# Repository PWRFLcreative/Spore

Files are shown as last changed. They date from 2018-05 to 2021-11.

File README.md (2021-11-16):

# Spore
The Spore system is a hardware and software platform that simplifies the process of creating with light. Each Spore is a softball-sized, WiFi-controlled, addressable, battery-operated, RGB LED module. This platform affords control of 1-1000+ Spores working together. The current version is optimized for about 100 Spores.

Spore was developed to showcase the potential of [Lightwork](https://github.com/PWRFLcreative/Lightwork). Lightwork uses computer vision to quickly map complex arrangements of addressable lights. Spore allows individually addressable LEDs to be placed in almost any arrangement, without any wiring for power and data. Used together, the the time to conceive and deploy a spatial light installation can be reduced from days to minutes.

With lots of options for input and output, Spore has many other possibilities for future uses. For example, wireless motor drivers that can be location mapped (using the LEDs + Lightwork), or accelerometer input to interact with individual lights, or reconfigurable, location aware sensor network interfaces, or lights that interpret the weather, or big Daniel Rozin-esque mirrors, etc...

## Basic Operation Requirements
  * Multicast capable Router + 802.11n Access Point (tested with Ubiquiti UAP-AC-LR + EdgeRouter X for ~100 devices). See network setup below.
  * JST-EH charger(s). 5V, ~520mA per Spore - we use a 5V 30A supply to charge 50 at a time
  * Source of sACN (E1.31) - generates the LED colors and transmits over the network
  * Between 1 and 100 Spores.

## Quick Start
1. Make sure you have at least one charged Spore, and have completed the [install guide](#installationrun-instructions) for the Config App and [Network setup](#network-setup).
2. Join your newly created network.
3. Once you’re all set up, open the Config App, and click `Send Server IP`. This broadcasts your computer's IP to all Spores on the network so that they can connect to you.
4. Next click `Scan for Changes`. This will scan your network and assign a unique address to all connected Spores, starting at `1`.
5. Click `Spore Status` to open the monitor, this will show you which Spores are connected, their battery level, and firmware version.
6. Use the mode switches to make sure they’re all communicating properly, e.g. switch from blackout to test mode.
7. Switch them into Normal Mode so they can receive sACN data.
8. Send sACN over multicast. We’ve used [QLC+](https://www.qlcplus.org/) and [sACN View](https://sourceforge.net/projects/sacnview/) to test, but you could also use something like Touchdesigner.

That’s it! Now that your Spores are set up and receiving sACN, you can map them with Lightwork, or use them as you’d like.

# Table of Contents
* [Hardware](#hardware)
  + [Feature List](#feature-list)
  + [Dev Requirements](#dev-requirements)
  + [PCB Build/Assembly/Ordering](#pcb-buildassemblyordering)
  + [Battery](#battery)
  + [Enclosure](#enclosure)
  + [Network Setup](#network-setup)
* [Firmware](#firmware)
  + [Dev Requirements](#dev-requirements)
  + [Compile/Upload Instructions](#compileupload-instructions)
* [Software](#software)
  + [Feature List](#feature-list)
  + [Dev Requirements](#dev-requirements)
  + [Installation/Run Instructions](#installationrun-instructions)
  + [OTA Firmware Updates](#ota-firmware-updates)
  + [Function Reference](#function-reference)
* [FAQ](#faq)
* [Known Issues & Workarounds](#known-issues--workarounds)
* [TODO](#todo)
* [Credits](#credits)

# Hardware
This section covers info on building and modifying the hardware, including the PCBs, batteries, prototyping, network setup, and enclosures.  

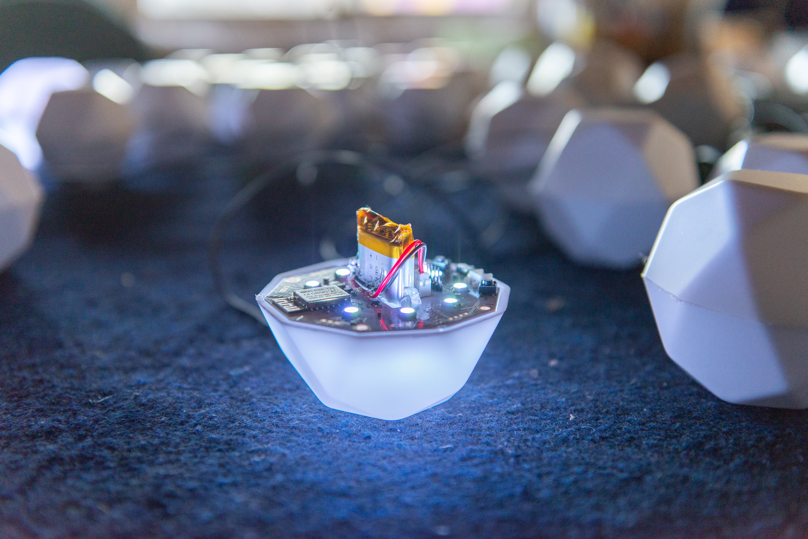
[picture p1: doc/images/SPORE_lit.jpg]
Image of Open Spores


## Feature List
  * ESP8266 - An Arduino-compatible microcontroller with built-in wifi
  * 16 built-in addressable RGB LEDs (sk6812)
  * Built-in battery charger (@500mA)
  * Slot for 1800mAh lipo (single cell, 103450)
  * Lasts 5+ hours w/ 1800mAh cell
  * Breakout pins for:
    + more LEDs
    + built-in MOSFET (~2.5A)
    + I2C
    + analog input (reads VBatt by default)
    + motor output
    + servo output
  * sACN (E1.31) LED control over network
  * Fades to black if no data received for more than 3 seconds
  * Over-The-Air (OTA) updateable firmware (all at once!)

## Dev Requirements
Install KiCad and open it! -- The PCB was designed in [KiCad 4](http://kicad.org/). We recently did test import to KiCad 5 which seemed OK, but we haven’t tested exported files/gerbers yet. We usually check our gerbers using [gerbv](https://sourceforge.net/projects/gerbv/) and/or GerbView included in KiCad 5 (the one in KiCad 4 is not great).  

### If You Don't Have a Spore:
If you want to play with the firmware without actually building one of the boards, this is our recommended test hardware (but use what you have):

  * [Adafruit HUZZAH Feather](https://www.adafruit.com/product/2821)
  * [NeoPixel ring](https://www.adafruit.com/product/1463)
  * A single cell LiPo, ~500-2000mAh (e.g. [Adafruit 500mAh](https://www.adafruit.com/product/1578))

Connect the NeoPixel `Data Input` to `RX` on HUZZAH; NeoPixel `Power 5V DC` to `BAT` on HUZZAH; NeoPixel `Power Signal Ground` to `GND` on HUZZAH. This setup works great for other form-factors. You could build a whole system using these or something similar if you wanted!

Connecting the LED 5V to the battery instead of 5V allows you to send 3.3V data without using a level shifter.

>**Note:** The LED data pin must go to GPIO3 for DMA (Direct Memory Access) to work. DMA lets the ESP send data to the LEDs without flickering during WiFi events. Otherwise, WiFi events take enough processor cycles to throw off the timing for the super-sensitive neopixel-compatible LEDs.. and it looks terrible!

## PCB Build/Assembly/Ordering
Some notes on ordering PCBs & parts:

I’ve had good experience getting assembled boards from [SAPA Technologies](http://www.sapatechs.com/) in the Vancouver BC area, and both assembled and unpopulated boards from PCBWay and Elecrow in China (but there are lots that are good). Local fabs generally do better, faster work, and allow you to come visit/send couriers/perform tests to make sure things happen right the first time; but it is naturally more expensive (I’ve found around 40-100% more). Cheaper chinese assemblers do a fine job, but it can take a little longer, communication is slow (time zones!), and you kinda get one shot at a time. One run I did in China had a silly mistake made by the fabricator that needed to be fully re-done twice. That put us over 6 weeks behind schedule. Apart from that, I recommend ordering at least 15% over what you actually need if ordering overseas, and more like 5-10% or less for local (depending on your test procedures and quantities).

>**Note:** Assembled means “with all the components soldered on”. Turnkey assembly means “source and buy all the components for me, and then solder them on”. Unpopulated (usually called PCB Manufacturing, or PCB Prototype) means, “just the PCB” and I am responsible for sourcing, buying, and soldering the components.

We usually order our components for local assembly or prototyping from Digikey. I recommend getting addressable LEDs from [Shiji Lighting](http://www.shiji-led.com/) if you are doing a bunch. They have consistent quality, excellent service, and good prices. You can use RGB or RGBW sk6812s for this board (RGBW will require a firmware modification). I think we didn’t use APA102s/sk9822s to save pins - we needed more free pins for an earlier design concept. That later changed but it was too late to switch back. Feel free to modify the boards for other LED protocols if you prefer!

#### PCB Requirements
When ordering prototype PCBs for Spore online:
  * 2 layers
  * HASL (cheaper) or ENIG/Immersion Gold Finish (a little more corrosion resistant)
  * 1.6mm thickness
  * White Solder Mask (PCB Color) - we think white helps reflect LED light outward vs dark PCB, but do what you want!
  * Leave other options at default

## Battery
SPOREs are designed to use a 103450, 1800mAh lipo battery with JST PHR-2 connector. You can use a different battery, just make sure the polarity of the PHR-2 connector matches, and it is at least 500mAh. The charge current is set with R6 on the Spore board.

We sourced our batteries from General Electronics Battery Co. (http://www.gebattery.co/) and were very happy with the service and quality. You may have to order 100+ batteries with them as they are an OEM supplier. Otherwise check Adafruit/Sparkfun or your local electronics or hobby shop (FYI shipping LiPos from USA to Canada is a pain in the neck).

To install the batteries, we built a simple wooden jig to center and square them in the PCB, tacked them with hot glue, and glued them in with RTV silicone. RTV silicone adheres well to the PCB and the battery, and absorbs shocks without releasing or cracking. It can also handle temperature swings without the bond weakening (e.g. maybe it’s cold outside then your LEDs heat up the board). Make sure it is RTV (room temperature vulcanizing), as neither Silicone I or Silicone II (typical bathroom or door/window sealants) have these properties.

>**Hot Tip:** You can usually find RTV Silicone in the automotive section of Canadian Tire or Home Depot. You can also get it at Princess Auto and Walmart. We love that stuff.

## Enclosure
Files for the enclosure are located [here](hardware/enclosureFiles/).

This includes a solid model for reference, a shell model that can be 3D printed or vacuum formed, and a 2D folded style shell that can be made from paper or translucent sheet material.

We made our shells of vacuum formed, ⅛”, white, Sign-Grade Lexan with the help of the folks at [Dimension 3](http://dimension3plastics.com/). Most of ours are hot-glued together (using a high-temperature gun), so we can easily reconfigure them, which has held up surprisingly well. For more permanent bonds, we’ve had good luck with heavy duty contact cement, 3M 4475 (industrial plastic adhesive), and BSI Maxi-Cure (high quality extra thick CA).

## Network Setup
First set up your network using the Edgerouter setup wizard. Then fire up the UniFi controller and partition your access point with an SSID and password that makes sense to you. We like the SSID: `SPORE`. Make sure the password is at least 8 characters. You'll need to enter these in the firmware `wifi_config.h` file in Arduino before uploading it.

Here are some details for optimizing the recommended Ubiquiti EdgeRouter X router and UAP-AC-xx access point to use multicast:

  * Disable AP multicast filter:  `config.mcast_filter_enabled=false` in config.properties ([Instructions](https://help.ubnt.com/hc/en-us/articles/205146040-UniFi-config-properties-File-Explanation))
  * Adjust AP multicast rate:     `config.mcast_rate.wlan.<your-ssid>=12` also in config.properties
  * in the Unifi Controller Interface Wireless Settings (`https://<your-ip>:8443/manage/site/default/settings/wlans/`), Click `edit/Advanced Options` and disable `Block LAN to WLAN Multicast and Broadcast Data`
  * in `edit/802.11 RATE AND BEACON CONTROLS`, check 2G `Enable Data Rate Control`, and set minimum to 12Mbps.

Additionally, the Unifi Controller and the server both want to use port 8080. Fortunately it is easy to adjust the Unifi controller (and it is not on all the time):

  * Change Unifi Controller http port from 8080 to 8081: `unifi.http.port=8081`in `system.properties` ([Instructions](https://help.ubnt.com/hc/en-us/articles/204910084-UniFi-Change-Default-Ports-for-Controller-and-UAPs))

# Firmware
This section contains information about the Spore firmware. It was written in Arduino which makes it pretty easy to tinker with! Every Spore uses the exact same firmware - addresses are modified using the Config App.

## Dev Requirements
Reminder: [How to Install Arduino Libraries](https://www.arduino.cc/en/Guide/Libraries)
  * [Arduino](https://www.arduino.cc/en/Main/Software) v1.8.7+
  * [Esp8266 Core](https://github.com/esp8266/Arduino#installing-with-boards-manager) v2.4.2 (may not work with older *or* newer version)
  * These Arduino libraries:
    + [Arduino JSON](https://github.com/bblanchon/ArduinoJson) v5.13.2
    + [WebSockets](https://github.com/Links2004/arduinoWebSockets) v2.1.1 (included because it has been modified for [async](https://github.com/Links2004/arduinoWebSockets#esp-async-tcp))
    + [NeoPixelBus](https://github.com/Makuna/NeoPixelBus) v2.3.2
    + [E131](https://github.com/forkineye/E131) v1.0.0
    + [ESPAsyncTCP](https://github.com/me-no-dev/ESPAsyncTCP) v1.2.0 (not in library manager)
    + [OSC](https://github.com/CNMAT/OSC) v1.3.5
    + [FastLED](https://github.com/FastLED/FastLED) v3.2.0
  * FTDI or USB-Serial with compatible pinout. 5V vcc required, 3.3v logic recommended (e.g. [Adafruit CP2104](https://www.adafruit.com/product/3309))

## Compile/Upload Instructions
  * Install Arduino, esp8266 core, and the above libraries
  * Set up Arduino Board options (`Arduino Menu-> Tools/`)  
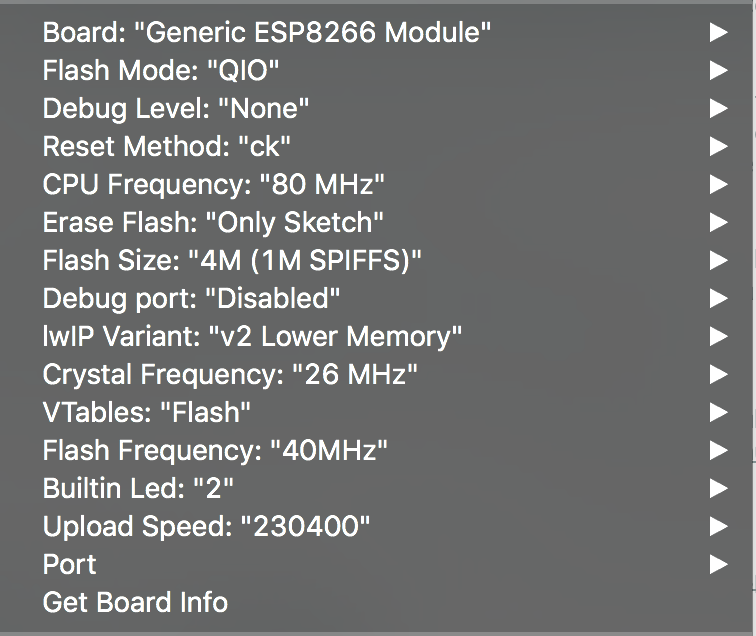
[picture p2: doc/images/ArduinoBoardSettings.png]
Arduino Board Settings
      
    *Note: the order of these settings is not always the same. I have no idea why.*
  * Plug in your FTDI (**check the orientation**) and select the correct port (some USB-Serial converters can handle a higher `Upload Speed`)
  * Set correct SSID and Password in `wifi_config.h` (changes in this file are not tracked by git, so you have to set on every new computer)
  * Open the Arduino Serial Monitor and set the baud rate to `115200`
  * Hold the bootload button while resetting the board, release bootload, then `Arduino Menu-> Sketch/Upload`.
  * ⚠️ **YOU MUST reset the board at least once after uploading new firmware with FTDI or OTA WILL NOT WORK**
  * Use the Serial Monitor to make sure the Spore is connecting to your network and receiving commands from the Config App. Disconnect the FTDI whenever you are done looking at debug printouts!

>**NOTE:** Some USB-Serial converters can prevent the LEDs from updating. If your LEDs seem stuck, unplug your FTDI/USB-Serial Converter.  
>Also: don't forget to download the driver for your USB-Serial converter if it is new!

# Software
The Spore Configuration App is a tool to configure and monitor the Spores. It was built in Node.js using the Electron framework. It should work on Mac, Windows, and GNU/Linux out of the box.

In the near future, we will export compiled binaries for all platforms, but for now, you need to install it using Node.js, and all dependencies should be automatically downloaded on `npm install` (see [below](#installationbuild-instructions)).

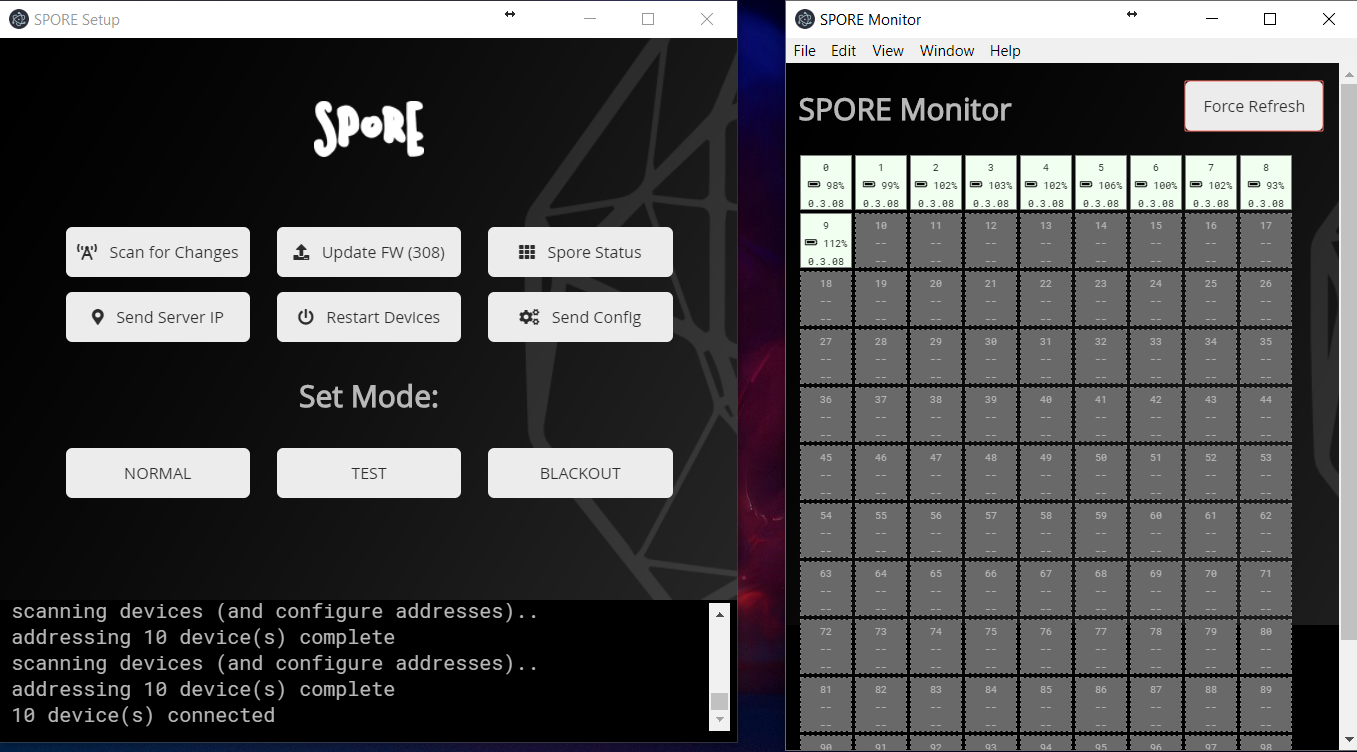
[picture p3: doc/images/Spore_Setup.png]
Configuration App Screenshot


## Feature List
  * Automatically set a unique address for each spore on the network
  * OTA firmware updates
  * Monitor battery level and status of connected spores
    + Red outline of a Spore indicates low battery warning
    + Flashing 🔌/⚠️ icons on a Spore indicate critical battery level
  * Identify individual spores (make a single one light up!) by clicking on it in the Monitor
  * Change modes on all spores:
    + Normal (receive sACN)
    + Test (light up with white, pulsing animation)
    + Blackout (turn off all LEDs)
  * Not required for normal operation of Spores - just a handy tool useful for reconfiguring and troubleshooting

## Dev Requirements
  * Node.js 8 LTS (we developed with v8.11, probably v8.12 is OK, but not yet tested)
  * Decent Javascript-friendly text editor (e.g. Atom, VS Code)

## Installation/Run Instructions
  1. Make sure Node.js is installed (type `node -v` in terminal to verify version. You need v8.11 or v8.12. DO NOT use v10.x+ unless you are ready to fix some stuff
  2. Clone or download and extract this repo to a nice home
  3. Open terminal/cmd
  4. cd to `<this repo>/configApp/` folder in terminal
  5. Type `npm install` to download and install dependencies (will take a few minutes)
  6. Type `npm start` to run
  7. Type `ctrl+c` in terminal to quit

## OTA Firmware Updates
The OTA Firmware updates the firmware on ALL SPOREs connected to the configurator. When the button is pressed, the server sends a message to each SPORE with the latest version number. The SPORE checks to see if this is newer than it’s current version. If yes, then it downloads and installs whichever firmware binary is in the `<this repo>/configApp/firmware/` folder.

  * in Arduino, export the firmware binary (`Menu-> Sketch/Export Compiled Binary`), and copy the output (`<this repo/firmware/Spore/Spore.ino.generic.bin`) to `configApp/firmware/`
  * rename the firmware file to `spore_fw.bin`
  * **After copy and rename:** open `config.json` in the `configApp` folder and change the value of `firmware_version` to match the constant `FW_VERSION` in the `settings.h` of the sensor firmware you just compiled. This number should always be a single `int`, i.e. for version 0.6.01: `601`, for version 1.0.05: `1005`.
  * restart the Config App
  * Press the `Check Firmware (###)` button in the App GUI

This could be more automatic in the future, but having multiple steps forces you to be very intentional about updating the firmware on a bunch of devices at once.

  * ⚠️ You can definitely soft-brick all of your devices by uploading untested firmware.
  * ⚠️ You can break OTA capabilities with untested firmware.
  * ⚠️ Firmware should be testing on a single device before OTA uploads.

Breaking OTA or soft-bricking devices requires updating firmware with FTDI for all of them - I’ve done it, and I don’t recommend it. This will be especially nasty if you've glued the enclosures together with a permanent adhesive.

## Function Reference
**Scan Network** (`websocket`) - Scan network for added or removed Spores, and assign addresses. Caution: this gives all Spores a unique address starting from 1, but in a totally random order. It will definitely change most (or all) addresses of any connected devices. This can ruin any mapping you may have already done!

**Update FW** (`websocket`) - Send command to Spores to check for new firmware. Be sure that your firmware binary works before OTA updating many Spores, or you may need to manually upload over FTDI to fix them.

**Spore Status** (`internal message`) - Opens the Monitor window that shows connected Spores, their firmware version, and battery status.

**Send Server IP** (`UDP OSC`) - broadcast your IP so any Spores on the network can connect to you (This will be automatic on scanning for changes, in a future update). Only needed when switching between computers or networks.

**Restart Devices** (`UDP OSC`)- broadcast a restart message to all Spores on the network. Because this is a UDP broadcast, it will even restart Spores that are having trouble connecting. Feel free to spam it a bit if you are really stuck. *Note: in `config.json`, you can change `reset_broadcast`. `true` brodcasts to all devices over `UDP OSC`, false sends only to connected devices via `websocket`*

**Send Config** (`websocket`) - Send config packet, containing the relevant data from config.json. Currently used to set boot mode on all Spores (Normal: 0, Test: 1, Blackout: 2). Spores store this info in EEPROM and will remember it between power cycles until you change it explicitly.

**Console** (`internal messages`) - This is an output of some system information. The count (`## spore(s) connected`) is not 100% reliable at the moment (related to handshake bug) but it's pretty close. The Monitor is more accurate.

### Modes:
**Normal:** Receive sACN. Fade to black if no sACN received for 3 seconds.

**Test:** Pulsing white animation. Useful to test connectivity and sync with many devices.

**Blackout:** Turn off all device LEDs. Use in conjunction with test mode to make sure all Spores are communicating properly.

### In the monitor:
**Force refresh** (`internal message`) - updates the monitor display. Usually only required after **scan network**. The fact that this is required is a bug. Eventually it will not be needed.

**Green Tiles** are connected Spores

**Grey Tiles** are unconnected Spores (if you only have 20 spores, 80 should be grey).

**Click a connected Spore** (`websocket`) to identify it with a pulsing white animation (Test Mode). Its tile will turn blue and animate a bit. Click again to "unidentify" it. Multiple Spores can be identified at once.

**Red Border Tiles** are Spores with a low battery. When the warning icon starts flashing, the battery is VERY low and they may start behaving badly (random restarts and flickers).

# FAQ
#### What is sACN?
Streaming ACN (sACN), aka ANSI E1.31, is a protocol developed by ESTA to efficiently transport DMX universes over a network. In other words, it is a standard way to control lights over a local network. It is comparable to ArtNET in many aspects. If you’ve ever been to a concert, the stage lights were controlled by DMX, ArtNet, and/or sACN.

Key features are that it uses multicast sockets which reduces network overhead and makes setup easier, and that it has a much higher universe limit of 63,999 vs Artnet’s 32,768. We have also been previously frustrated by apparently mixed standards/version of Artnet (read: it’s broken AF), whereas sACN is an ANSI standard and the implementations we’ve found all seem to work with each other.

#### Do I need the Spore Configurator App?
Maybe. The config app simplifies addressing and firmware updates on lots of devices. You could manage this manually for a small number of devices (i.e. hard-code the address and program with an FTDI). In general, once the devices have been configured once, you don’t need the app running. However, it is very helpful to be able to see connection status, battery status, and firmware version. Also, the remote `Restart Devices` and `Test Mode` are both quick ways to solve problems in the field (“Have you tried turning it off and on?”).

#### Do I need a fancy and expensive router and/or access point?
Depends! For large numbers of devices, access point and router configuration options become more important. In theory, with some good network administration, you should be able to control 1000+ SPOREs. For only a few devices (< 20 or so), any router that supports multicast should work fine, but routers are picky and weird. We can’t promise anything but it doesn’t hurt to try! If you are using your home router, maybe turn off Netflix first.

#### What software can control the SPORE LEDs?
Anything that can send sACN/e1.31 over network. We’ve tested with Lightwork (our own project built in Processing), Touchdesigner (DMX Out Chop), Processing (e131 library), and QLC+ (open source lighting control app). LED control software like Madrix or mapping software like MadMapper should also work. You can use tools like the Open Lighting Architecture (OLA, https://www.openlighting.org/ola/) to communicate with software like Max/MSP, PureData, etc. You could also write some of your own stuff - Arduino, Node.js, c++, python, and others all have sACN libraries available. Or you could modify the SPORE firmware to receive OSC or ArtNet instead.

>TD Lightwork: https://github.com/timrolls/TD-Lightwork

# Known Issues & Workarounds
**Multiple websockets handshake thing** - For some reason, devices sometimes send many "connect" handshakes in a row, even after they have connected. This is probably a firmware problem related to the ESPAsyncTCP + Async Websockets libraries. For now, if a device isn’t connected or repeatedly connects, or repeatedly disconnects - send the `restart devices` command (there is a behaviour in the server that attempts to filter this out, it may take a couple of minutes if your server or router has crashed or been unplugged during operation)

**Address Collision** - currently the system allows multiple devices to have the same address. This has been intentionally allowed for now. If you want each device to have a unique address, press `scan for changes`. HOWEVER, this will readdress everything which will most likely BREAK your mapping (if applicable, e.g. Lightwork). Make sure you have all your devices figured out and address before you map them with Lightwork.

**Changing the Config App `config.json` file** - Whenever this is changed, you should restart the App. Making this more robust is on the future todo list, but it should be so rarely used that restarting the app isn’t the end of the world.

See github issues for more!

# TODO:
Here are some things that might be done in the future. If you want to contribute to the project it might be a good place to start! In no particular order:

  - [ ] See github issues for broken things!
  - [ ] Export Config App as standalone app. For now, you need to install and run it as a dev from your chosen terminal. See the Electron documentation.
  - [ ] Make a SPORE DEMO mode. This should show off capabilities when there is no server or wifi available, or on a button press.
  - [ ] Migrate to Node.js 10 (wait until October for LTS)
  - [ ] Make the firmware server more automatic (drag & drop, rename file, auto-extract version or enter version in GUI)
  - [ ] Make editing the config.json file work better - could be auto-restart server, could be notifies with a warning whenever it changes (i.e. “config file has changed, server restart required”), could be dynamically reload all config values.
  - [ ] Add sleep mode to SPOREs (currently sleep mode is labelled as “blackout” which is also helpful). Would be good to be able to sleep the spores to save battery power if they need to be installed ahead of time. Decisions need to be made about how long between wakeups (to connect to network and check if it’s time to get to work), and which sleep mode to go into.
  - [ ] SPOREs receive other data - Maybe you send it Audio-Reactive OSC or something?
  - [ ] SPOREs transmit streaming data (i.e. streaming their sensor data) - what format, how fast, etc.
  - [ ] Add ArtNet support (we chose sACN because it is more robust, but ArtNet is more widely supported)
  - [ ] Port Config App to Android (wouldn’t it be nice if this whole thing were running on your phone?) - or fork to create a non-electron version that serves the GUI to a browser etc.

## Credits

Spore is a collaboration between [Tangible Interaction](http://www.tangibleinteraction.com/) and [Makerlabs](http://www.makerlabs.com/), made possible by the [Creative BC Interactive Fund](https://www.creativebc.com/programs/development-funding/interactive-fund).

Individual contributors include:

  * Tim Rolls - Creative Director and Developer
  * Leó Stefánsson - Lightwork Developer
  * Brendan Matkin - Spore Hardware, Firmware, Concept
  * Alex Beim - Spore Concept
  * Andrea Buttarini - Spore Design

Special thanks to generous help from volunteers, including:

  * Yasu Harada
  * Marie Harada
  * Noel Rubin
  * Ikbel Hammami

Creative BC Logo

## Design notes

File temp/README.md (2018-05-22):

# Spore
Spore WiFi LED module. Firmware and Hardware.

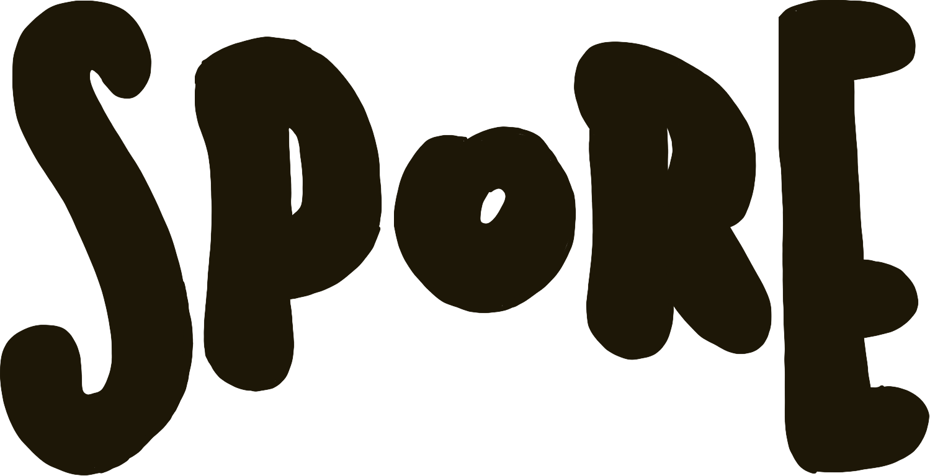
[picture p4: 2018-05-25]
hardware/drawings+img/SPORE.png

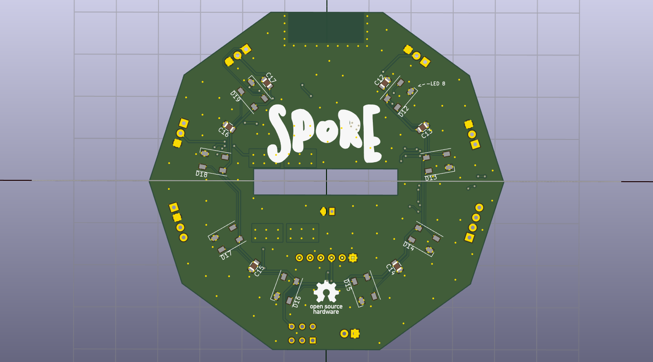
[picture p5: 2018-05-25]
hardware/drawings+img/SPORE_back_v0.0.1.png

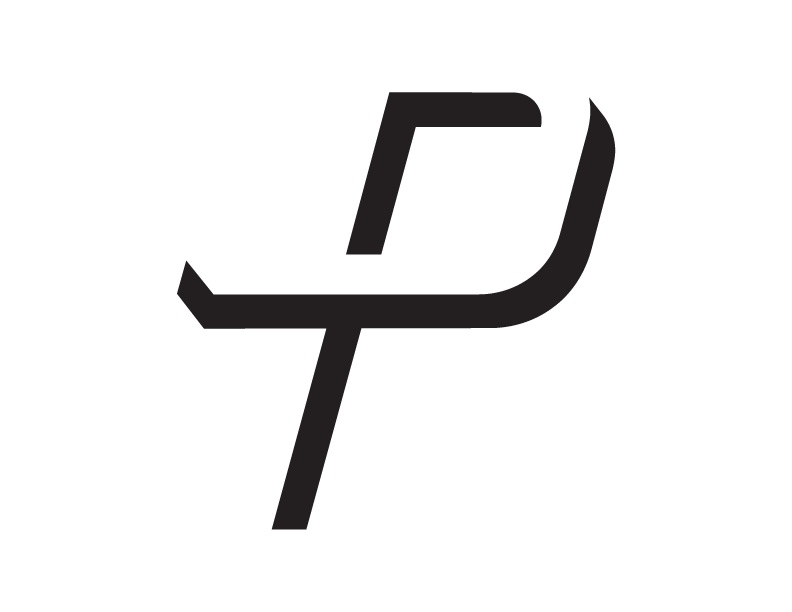
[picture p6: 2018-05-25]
hardware/drawings+img/PWRFL-P-Black.png

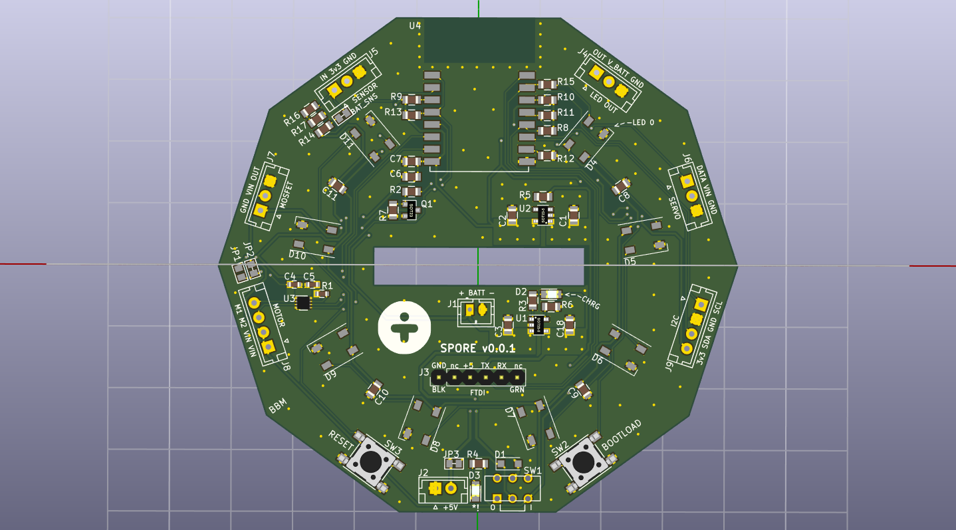
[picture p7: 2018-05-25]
hardware/drawings+img/SPORE_front_v0.0.1.png

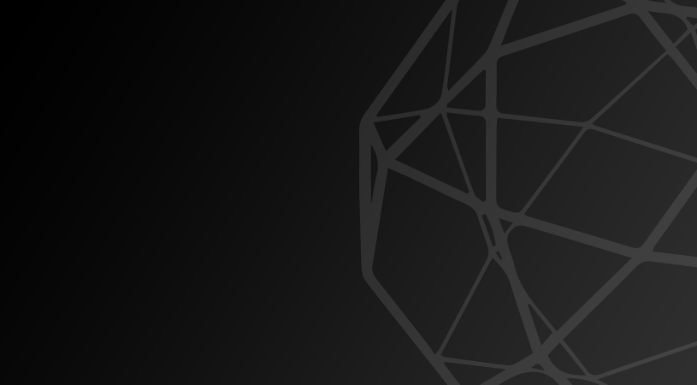
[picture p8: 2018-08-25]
configApp/img/Spore-BG.png

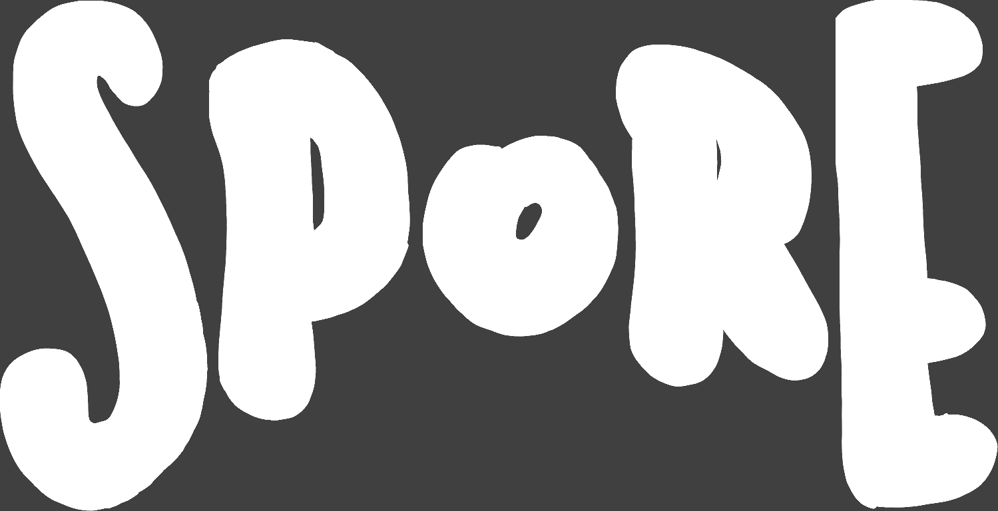
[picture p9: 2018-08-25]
configApp/img/SPORE-White.png

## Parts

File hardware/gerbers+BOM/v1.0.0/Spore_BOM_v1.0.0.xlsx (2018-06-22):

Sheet: Spore_proto
Reference | Value | Footprint | Datasheet | Max ESR | NOTES | TOTALS
C1 | 1.0uF | Capacitors_SMD:C_0805 |  | 1.5 Ohm |  | 0.1uf (0603) | 2 | x
C10 | 1.0uF | Capacitors_SMD:C_0805 |  | 1.5 Ohm |  | 0.1uf (0805) | 2 | x
C11 | 1.0uF | Capacitors_SMD:C_0805 |  | 1.5 Ohm |  | 1.0uf (0805) | 11 | x
C12 | 1.0uF | Capacitors_SMD:C_0805 |  | 1.5 Ohm |  | 2.2uf (0805) | 1 | ~
C13 | 1.0uF | Capacitors_SMD:C_0805 |  | 1.5 Ohm |  | 10uF (0805) | 1 | ~
C14 | 1.0uF | Capacitors_SMD:C_0805 |  | 1.5 Ohm |  | 22uf (0805) | 1 | ~
C15 | 1.0uF | Capacitors_SMD:C_0805 |  | 1.5 Ohm
C16 | 1.0uF | Capacitors_SMD:C_0805 |  | 1.5 Ohm |  | 10k (0603) | 1 | ~
C17 | 1.0uF | Capacitors_SMD:C_0805 |  | 1.5 Ohm |  | 330R (0805) | 1 | ~
C18 | 0.1uF | Capacitors_SMD:C_0805 |  |  |  | 1k (0805) | 1 | x
C2 | 2.2uF | Capacitors_SMD:C_0805 |  | 1.5 Ohm |  | 2k (0805) | 3 | ~
C3 | 10uF | Capacitors_SMD:C_0805 |  | 1.5 Ohm |  | 4.7k (0805) | 2 | ~
C4 | 0.1uF | Capacitors_SMD:C_0603 |  |  | DRV | 10k (0805) | 6 | x
C5 | 0.1uF | Capacitors_SMD:C_0603 |  |  | DRV | 100k (0805) | 2 | ~
C6 | 22uF | Capacitors_SMD:C_0805 |  |  |  | 220k (0805) | 1 | ~
C7 | 0.1uF | Capacitors_SMD:C_0805
C8 | 1.0uF | Capacitors_SMD:C_0805 |  | 1.5 Ohm |  | MBR120 (123F) | 1 | ~
C9 | 1.0uF | Capacitors_SMD:C_0805 |  | 1.5 Ohm |  | SK6812 (5050) | 16 | ~
D1 | MBR120 | Diodes_SMD:D_SOD-123F |  |  |  | White LED (0805) | 2 | ~
D10 | SK6812-RGBW | TI_led:LED_SK6812_PLCC4_5.0x5.0mm_P3.2mm
D11 | SK6812-RGBW | TI_led:LED_SK6812_PLCC4_5.0x5.0mm_P3.2mm |  |  |  | JST PH 2 | 1 | ~
D12 | SK6812-RGBW | TI_led:LED_SK6812_PLCC4_5.0x5.0mm_P3.2mm |  |  |  | JST EH 2 | 1 | ~
D13 | SK6812-RGBW | TI_led:LED_SK6812_PLCC4_5.0x5.0mm_P3.2mm |  |  |  | 6 pin header (2.54mm) | 1 | x
D14 | SK6812-RGBW | TI_led:LED_SK6812_PLCC4_5.0x5.0mm_P3.2mm |  |  |  | JS202011AQN (PTH switch) | 1 | ~
D15 | SK6812-RGBW | TI_led:LED_SK6812_PLCC4_5.0x5.0mm_P3.2mm |  |  |  | PTS645 (SMD Switch) | 2 | ~
D16 | SK6812-RGBW | TI_led:LED_SK6812_PLCC4_5.0x5.0mm_P3.2mm
D17 | SK6812-RGBW | TI_led:LED_SK6812_PLCC4_5.0x5.0mm_P3.2mm |  |  |  | DMG2302UK-7 (SOT-23) | 1 | ~
D18 | SK6812-RGBW | TI_led:LED_SK6812_PLCC4_5.0x5.0mm_P3.2mm |  |  |  | MCP73831 (SOT23-5) | 1 | ~
D19 | SK6812-RGBW | TI_led:LED_SK6812_PLCC4_5.0x5.0mm_P3.2mm |  |  |  | AP2112 (SOT23-5) | 1 | ~
D2 | WHITE | LEDs:LED_0805 |  |  |  | DRV883x (DFN-8 2x2, 0.5mm) | 1 | ~
D3 | WHITE | LEDs:LED_0805 |  |  |  | ESP-12E | 1 | x
D4 | SK6812-RGBW | TI_led:LED_SK6812_PLCC4_5.0x5.0mm_P3.2mm
D5 | SK6812-RGBW | TI_led:LED_SK6812_PLCC4_5.0x5.0mm_P3.2mm
D6 | SK6812-RGBW | TI_led:LED_SK6812_PLCC4_5.0x5.0mm_P3.2mm
D7 | SK6812-RGBW | TI_led:LED_SK6812_PLCC4_5.0x5.0mm_P3.2mm
D8 | SK6812-RGBW | TI_led:LED_SK6812_PLCC4_5.0x5.0mm_P3.2mm
D9 | SK6812-RGBW | TI_led:LED_SK6812_PLCC4_5.0x5.0mm_P3.2mm
J1 | BATT | Connectors_JST:JST_PH_B2B-PH-K_02x2.00mm_Straight
J2 | 5V IN | Connectors_JST:JST_EH_B02B-EH-A_02x2.50mm_Straight
J3 | FTDI to ESP | Pin_Headers:Pin_Header_Straight_1x06_Pitch2.54mm
J4 | LED OUT | Connectors_JST:JST_EH_B03B-EH-A_03x2.50mm_Straight
J5 | SENSOR | Connectors_JST:JST_EH_B03B-EH-A_03x2.50mm_Straight
J6 | SERVO | Connectors_JST:JST_EH_B03B-EH-A_03x2.50mm_Straight
J7 | MOSFET | Connectors_JST:JST_EH_B03B-EH-A_03x2.50mm_Straight
J8 | MOTOR | Connectors_JST:JST_EH_B04B-EH-A_04x2.50mm_Straight
J9 | I2C | Connectors_JST:JST_EH_B04B-EH-A_04x2.50mm_Straight
JP1 | 3v3_EN | TI_conn:JMP_NO
JP2 | EXT_EN | TI_conn:JMP
JP3 | EXT_EN | TI_conn:JMP
JP4 | BATT_SENSE | TI_conn:JMP
Q1 | DMG2302UK-7 | TO_SOT_Packages_SMD:SOT-23 |  |  | MOSFET
R1 | 10k | Capacitors_SMD:C_0603 |  |  | DRV
R10 | 2k | Capacitors_SMD:C_0805 |  |  | I2C
R11 | 2k | Capacitors_SMD:C_0805 |  |  | I2C
R12 | 10k | Capacitors_SMD:C_0805
R13 | 10k | Capacitors_SMD:C_0805
R14 | 100k | Capacitors_SMD:C_0805
R15 | 330 | Capacitors_SMD:C_0805
R16 | 220k | Capacitors_SMD:C_0805
R17 | 100k | Capacitors_SMD:C_0805
R2 | 1k | Capacitors_SMD:C_0805
R3 | 4.7k | Capacitors_SMD:C_0805 |  |  | LED ind.
R4 | 4.7k | Capacitors_SMD:C_0805 |  |  | LED ind.
R5 | 10k | Capacitors_SMD:C_0805
R6 | 2k | Capacitors_SMD:C_0805 |  |  | Charge Prog.
R7 | 10k | Capacitors_SMD:C_0805
R8 | 10k | Capacitors_SMD:C_0805
R9 | 10k | Capacitors_SMD:C_0805
SW1 | JS202011AQN | TI_switches:SW_Micro_DPDT |  |  | PWR
SW2 | Bootload | Buttons_Switches_SMD:SW_SPST_PTS645
SW3 | Reset | Buttons_Switches_SMD:SW_SPST_PTS645
U1 | MCP73831 | TO_SOT_Packages_SMD:SOT-23-5 |  |  | Charger
U2 | AP2112 | TO_SOT_Packages_SMD:SOT-23-5 |  |  | Regulator
U3 | DRV883x | Housings_DFN_QFN:DFN-8-1EP_2x2mm_Pitch0.5mm |  |  | Motor Driver
U4 | ESP-12E | ESP8266:ESP-12E_Brendan |  |  | WiFi

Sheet: BOM
Reference | Description | Footprint | P/N | Digikey | Quantity
C7, C18 | 0.1uf | 0805 |  |  | 2
C1, C8, C9, C10, C11, C12, C13, C14, C15, C16, C17 | 1.0uF | 0805 |  |  | 11
C2 | 2.2uF | 0805 |  |  | 1
C3 | 10uF | 0805 |  |  | 1
C6 | 22uF | 0805 |  |  | 1
R15 | 330R | 0805 |  |  | 1
R2 | 1k | 0805 |  |  | 1
R6 | 2k | 0805 |  |  | 1
R3, R4 | 4k7 | 0805 |  |  | 2
R5, R7 R8, R9, R12, R13 | 10k | 0805 |  |  | 6
R17 | 100k | 0805 |  |  | 1
R14, R16 | 220k | 0805 |  |  | 2
D1 | MBR120 | 123F | MBR120LSFT3G | MBR120LSFT3GOSCT-ND (https://www.digikey.ca/product-detail/en/on-semiconductor/MBR120LSFT3G/MBR120LSFT3GOSCT-ND/6181718) | 1
D4 - D19 | SK6812-RGB | 5050 | SK6812-RGB OR WS2812B | 1528-2388-ND (https://www.digikey.ca/product-detail/en/adafruit-industries-llc/3094/1528-2388-ND/6058485) | 16
D2, D3 | White LED | 0805 | QBLP631-IW | 1516-1085-1-ND (https://www.digikey.ca/product-detail/en/qt-brightek-qtb/QBLP631-IW/1516-1085-1-ND/4814812) | 2
J1 | JST-PH-2 | 2x2.0mm | B2B-PH-K-S(LF)(SN) | 455-1704-ND (https://www.digikey.ca/product-detail/en/jst-sales-america-inc/B2B-PH-K-S(LF)(SN)/455-1704-ND/926611) | 1
J2 | JST-EH-2 | 2x2.54mm | S2B-EH(LF)(SN) | 455-1625-ND (https://www.digikey.ca/product-detail/en/jst-sales-america-inc/S2B-EH(LF)(SN)/455-1625-ND/926533) | 1
J3 | 6 pin header | 6x2.54mm |  |  | 1
SW1 | DPDT Switch | PTS645-SMD | JS202011AQN | 401-2000-ND (https://www.digikey.ca/product-detail/en/c-k/JS202011AQN/401-2000-ND/1640096) | 1
SW2, SW3 | Tactile Switch | PTS645-SMD | PTS645SH50SMTR92 LFS | CKN9085CT-ND (https://www.digikey.ca/product-detail/en/c-k/PTS645SH50SMTR92-LFS/CKN9085CT-ND/1146817) | 2
Q1 | N-ch MOSFET | SOT23 | DMG2302UK-7 | DMG2302UK-7DICT-ND (https://www.digikey.ca/product-detail/en/diodes-incorporated/DMG2302UK-7/DMG2302UK-7DICT-ND/6010163) | 1
U2 | 3.3v Regulator | SOT23-5 | AP2112K-3.3TRG1 | AP2112K-3.3TRG1DICT-ND (https://www.digikey.ca/product-detail/en/diodes-incorporated/AP2112K-3.3TRG1/AP2112K-3.3TRG1DICT-ND/4505257) | 1
U1 | LiPo charge controller | SOT23-5 | MCP73831T-2ACI/OT | MCP73831T-2ACI/OTCT-ND (https://www.digikey.ca/product-detail/en/microchip-technology/MCP73831T-2ACI-OT/MCP73831T-2ACI-OTCT-ND/1979802) | 1
U4 | ESP8266 ESP-12S | ESP-12x | ESP-12S | 1528-1438-ND (https://www.digikey.ca/product-detail/en/adafruit-industries-llc/2491/1528-1438-ND/5761206) | 1

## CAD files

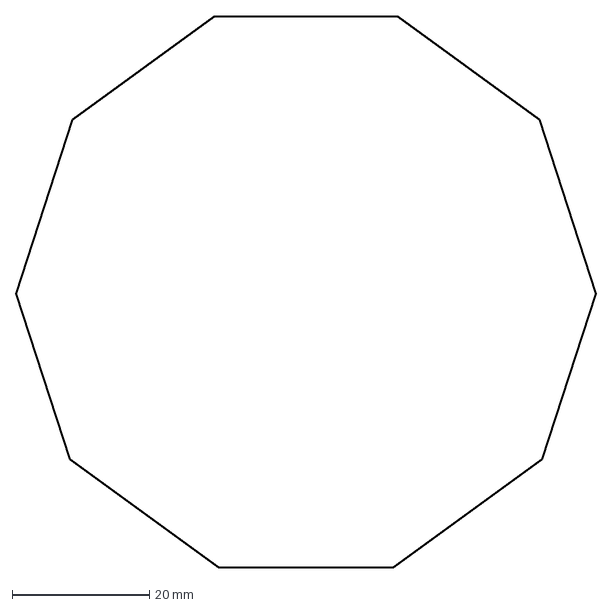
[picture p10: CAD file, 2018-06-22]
hardware/drawings+img/#PCB_mm.dxf
84.5 x 80.3 mm

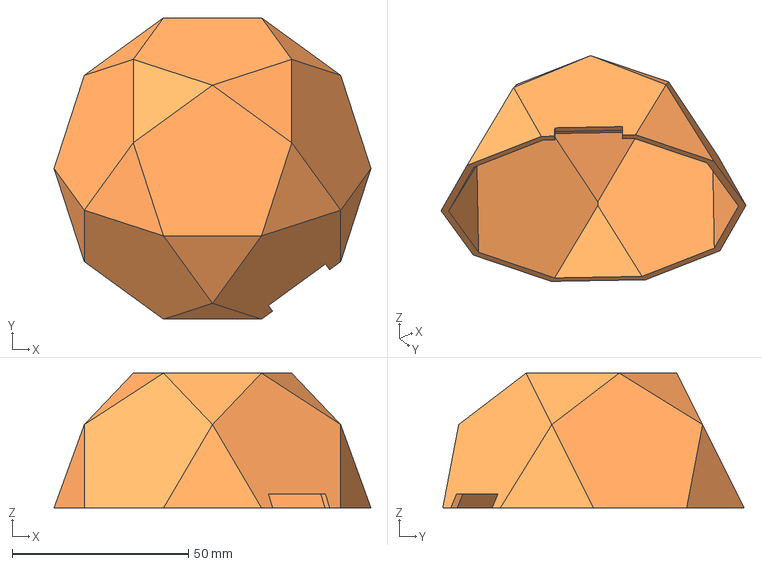
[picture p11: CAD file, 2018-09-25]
hardware/enclosureFiles/Spore Shell 2 of 2 ( with slot ).stp
90.0 x 85.6 x 38.3 mm

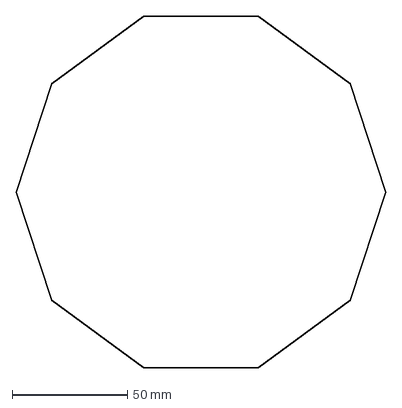
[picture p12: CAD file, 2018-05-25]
hardware/drawings+img/dodecagon_test.dxf
160.0 x 152.2 mm

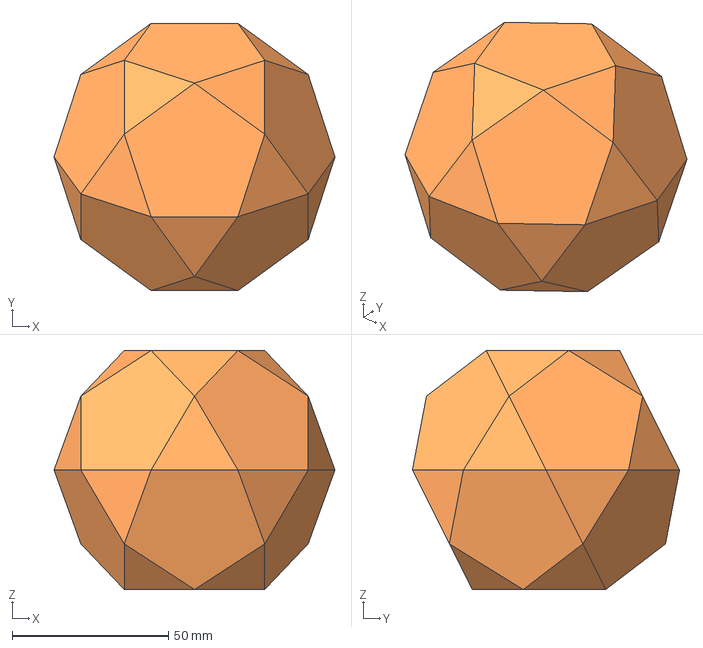
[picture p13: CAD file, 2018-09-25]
hardware/enclosureFiles/Spore Solid.stp
90.0 x 85.6 x 76.6 mm

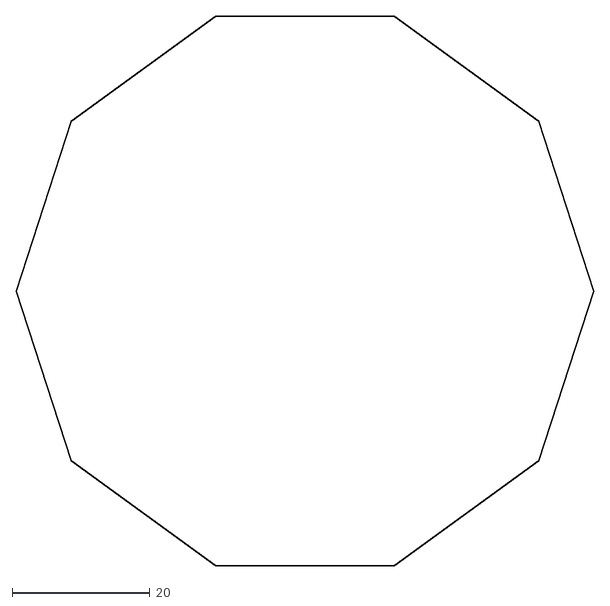
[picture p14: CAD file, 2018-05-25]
hardware/drawings+img/dodecagon_test_84mmD.dxf
84.0 x 79.9

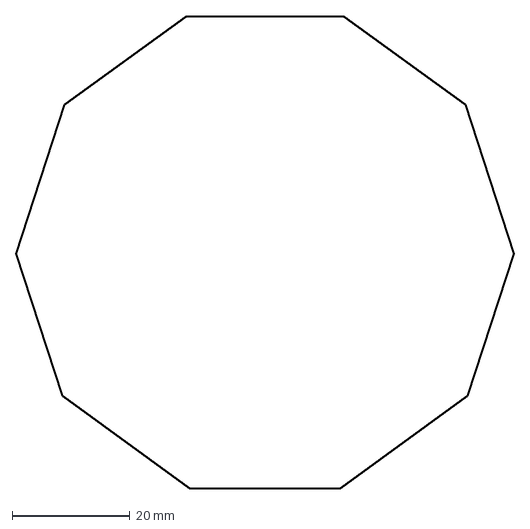
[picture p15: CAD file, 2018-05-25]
hardware/drawings+img/SPORE_PCB_mm.dxf
84.5 x 80.3 mm

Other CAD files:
hardware/enclosureFiles/Spore Shell 1 of 2.stp

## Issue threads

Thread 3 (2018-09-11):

wss.clients.size reporting 1 extra client?

brendanmatkin, 2018-09-11:
in cases with a poor connection, wss.clients.size is too big - i.e. a single device connected and wss.clients.size (can be seen in status console) is 2

brendanmatkin, 2018-09-17:
may also be related to #13

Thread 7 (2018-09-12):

"force refresh" not working (config monitor)

brendanmatkin, 2018-09-12:
used to work, now it doesn't. Have to close and open monitor window after "scan for changes" to get rid of extra, no longer existing devices

brendanmatkin, 2018-09-14:
Additionally, monitor is showing a device in multiple locations after a scan. Closing and re-opening the monitor fixes this.

ALSO some devices flicker in the monitor, but they are not actually loosing their websocket connection.

Need to check the logic in the messaging system between the windows.

brendanmatkin, 2018-09-17:
fixed. Should improve behaviour. see #14

Closed 2018-09-17.

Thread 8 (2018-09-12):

SPORES crash on auto reset when rx change serverIP

brendanmatkin, 2018-09-12:
`exception(28): LoadProhibited: A load referenced a page mapped with an attribute that does not permit loads`
happens with a slightly different stack trace each time.

Related to
```
if (_serverChanged) {
    EEPROM.commit();
    webSocket.begin(serverIP.toString(), wsPort, "/");
    Serial.printf("[osc] New Websocket server at: %s:%u\n", serverIP.toString().c_str(), wsPort);
    //delay(10);
    ESP.restart();
  }
```
in `serverControl.h`

brendanmatkin, 2018-09-14:
This is actually caused by unstable power supply - found by testing without batteries (#9). Throw a big cap on there if you are going to use them without batteries. Closing.

Closed 2018-09-14.

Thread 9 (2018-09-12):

Hardware needs more bulk capacitance?  (if not battery operated)

brendanmatkin, 2018-09-12:
When using without the battery (and just USB), getting weird crashes and inconsistent exceptions. Probably only when using with LEDs - might be related to state of JP3?

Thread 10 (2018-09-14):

Occasional SPORE stuck in ws connect loop

brendanmatkin, 2018-09-14:
On configapp restart, some devices will continually reconnect to the config app on every ping (not sure if hardware ping or config ping). Might be related to #3.

Not sure if this is a firmware issue or config app issue.

brendanmatkin, 2018-09-14:
power-cycling the affected SPORE fixes it.

brendanmatkin, 2018-09-17:
Looks like firmware is sending multiple handshakes. Likely related to async mode (but we can't ditch that now). This might actually be a bug in the library.

Added a "restart devices" ability in the config app as a temp workaround.

Also working on some other config app behaviours that check for already connected devices trying to reconnect and force terminate them until they stop. This is happening too fast though there needs to be some kind of delay in the firmware.

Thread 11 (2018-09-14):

battery voltage math might be wrong

brendanmatkin, 2018-09-14:
SPOREs are power down at a reported remaining capacity of between 20%-25%. Obviously this is wrong! Check the math on both the firwmare and the config app.

brendanmatkin, 2018-09-15:
Not 100% accurate, but remapped the values from 2.75-4.2 to 3.3-4.2, as lower than ~3.1-3.2 and things start to brown out a bit (it fluctuates).

Allowing negative % (i.e. -10% battery life) and adding a flashing plug-in warning below 5% in the config app interface.

Closed 2018-09-15.

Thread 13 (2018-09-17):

do not report "## devices connected" in heartbeat()

brendanmatkin, 2018-09-17:
call a function on interval that checks if wss.clients.size has changes and report.

Currently this happens in heartbeat - this can NEVER reach zero because if zero devices are connected then you will never get a pong and heartbeat won't be called!

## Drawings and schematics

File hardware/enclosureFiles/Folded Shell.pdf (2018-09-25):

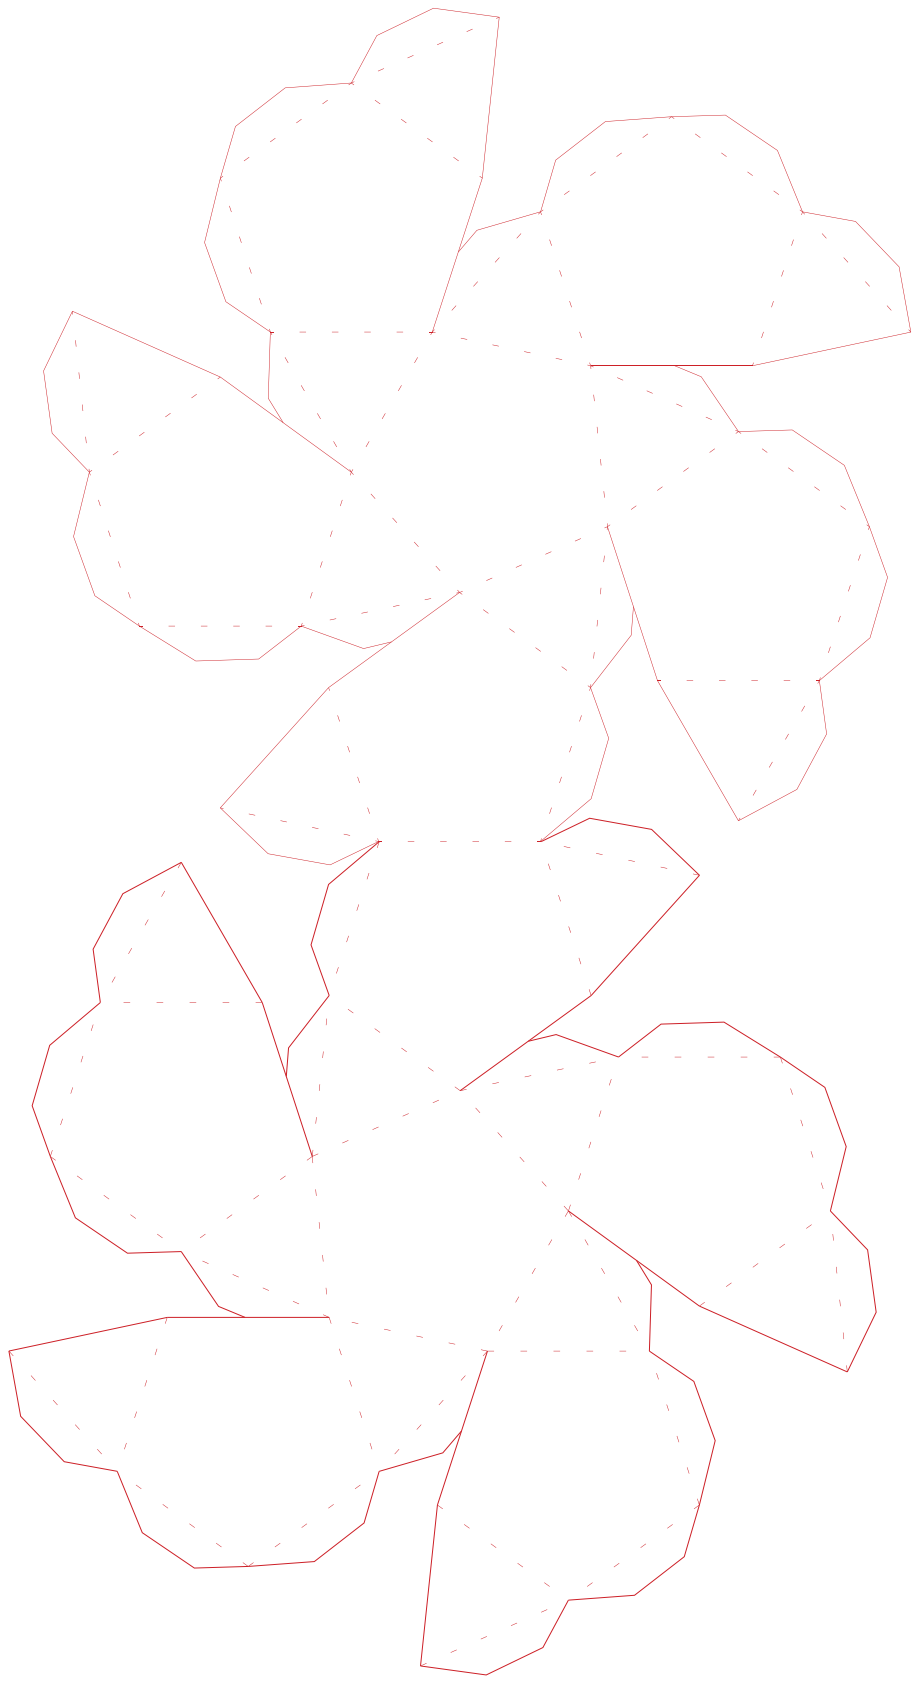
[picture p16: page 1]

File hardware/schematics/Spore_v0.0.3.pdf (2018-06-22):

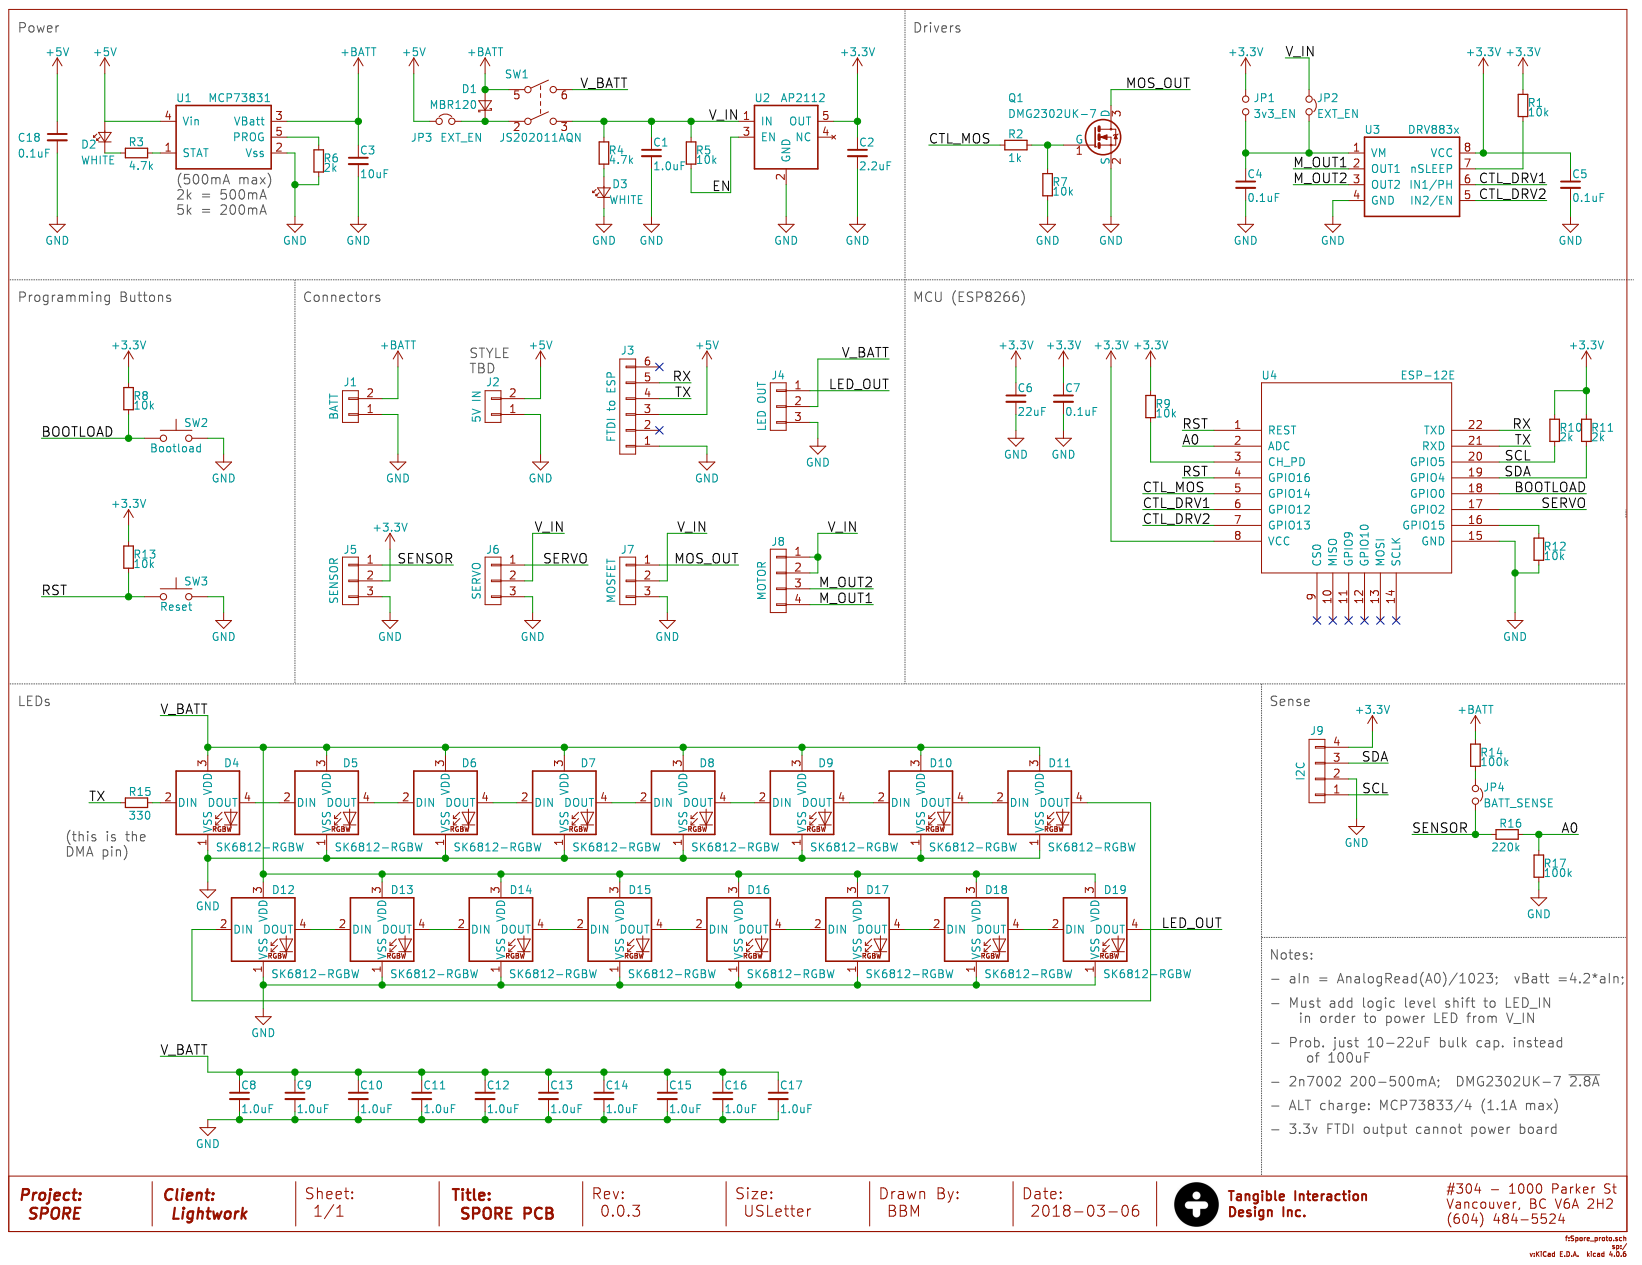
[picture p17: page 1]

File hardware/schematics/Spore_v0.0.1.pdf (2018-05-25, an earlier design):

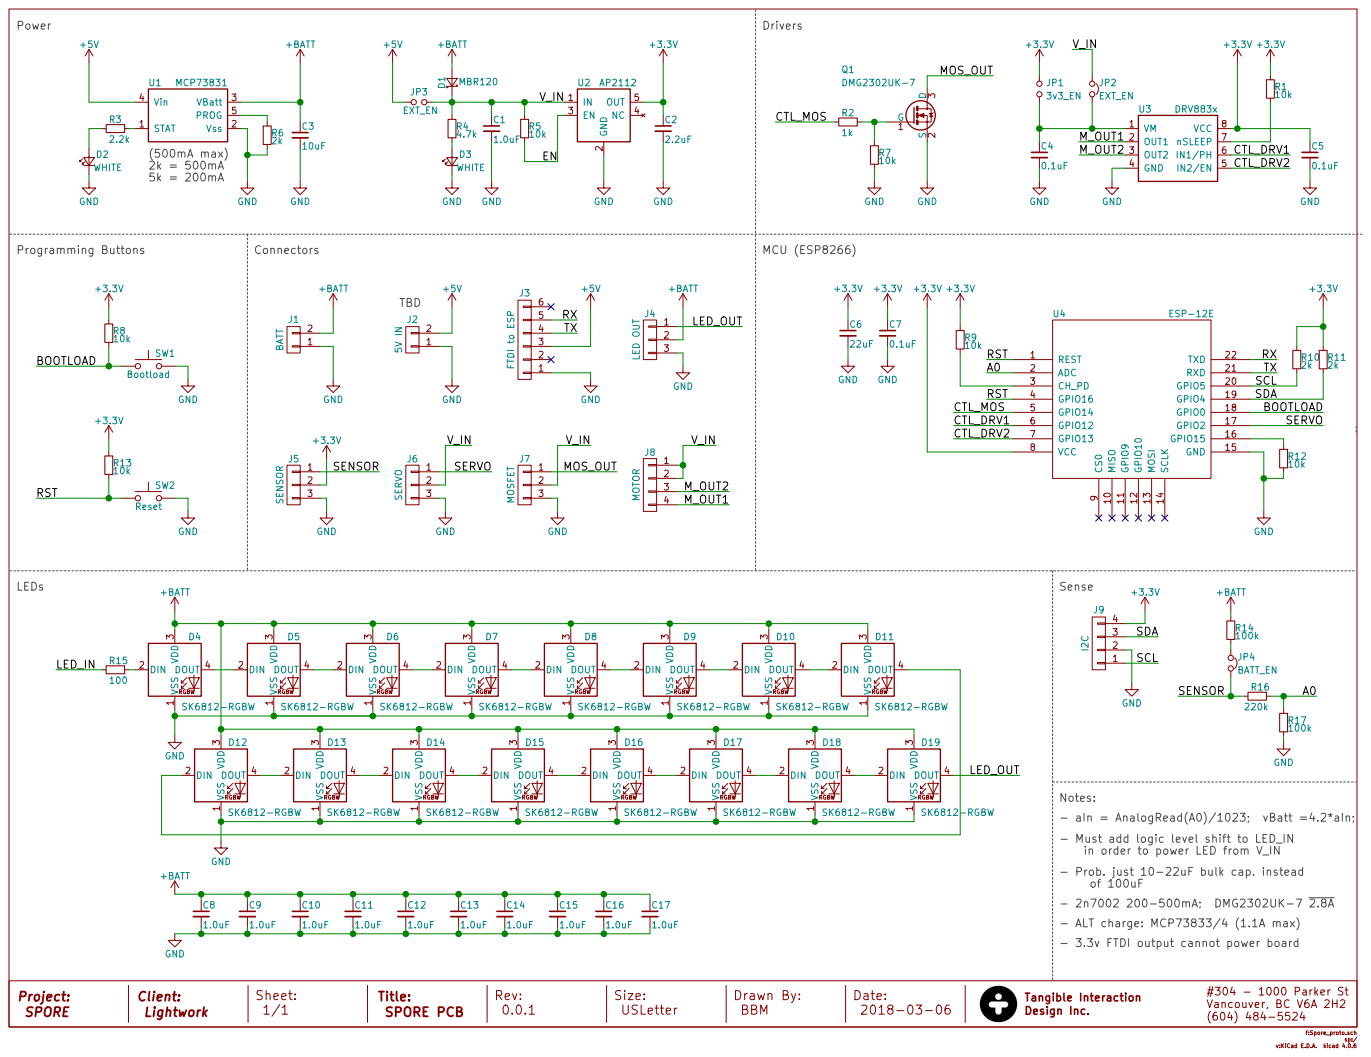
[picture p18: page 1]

9 MISO 10 GPIO5 20 GPIO9 11 RXD 21 GPIO10 12 TXD 22 MOSI 13 SCLK 14 GND 15 GPIO15 16 GPIO2 17 GPIO0 18 GPIO4 19 U4 ESP-12E Power Programming Buttons MCU (ESP8266) 1
+BATT GND

- aIn = AnalogRead(A0)/1023; vBatt =4.2*aIn; C8

- Must add logic level shift to LED_IN
in order to power LED from V_IN
- Prob. just 10-22uF bulk cap. instead
- 2n7002 200-500mA; DMG2302UK-7 2.8A
- ALT charge: MCP73833/4 (1.1A max)
- 3.3v FTDI output cannot power board

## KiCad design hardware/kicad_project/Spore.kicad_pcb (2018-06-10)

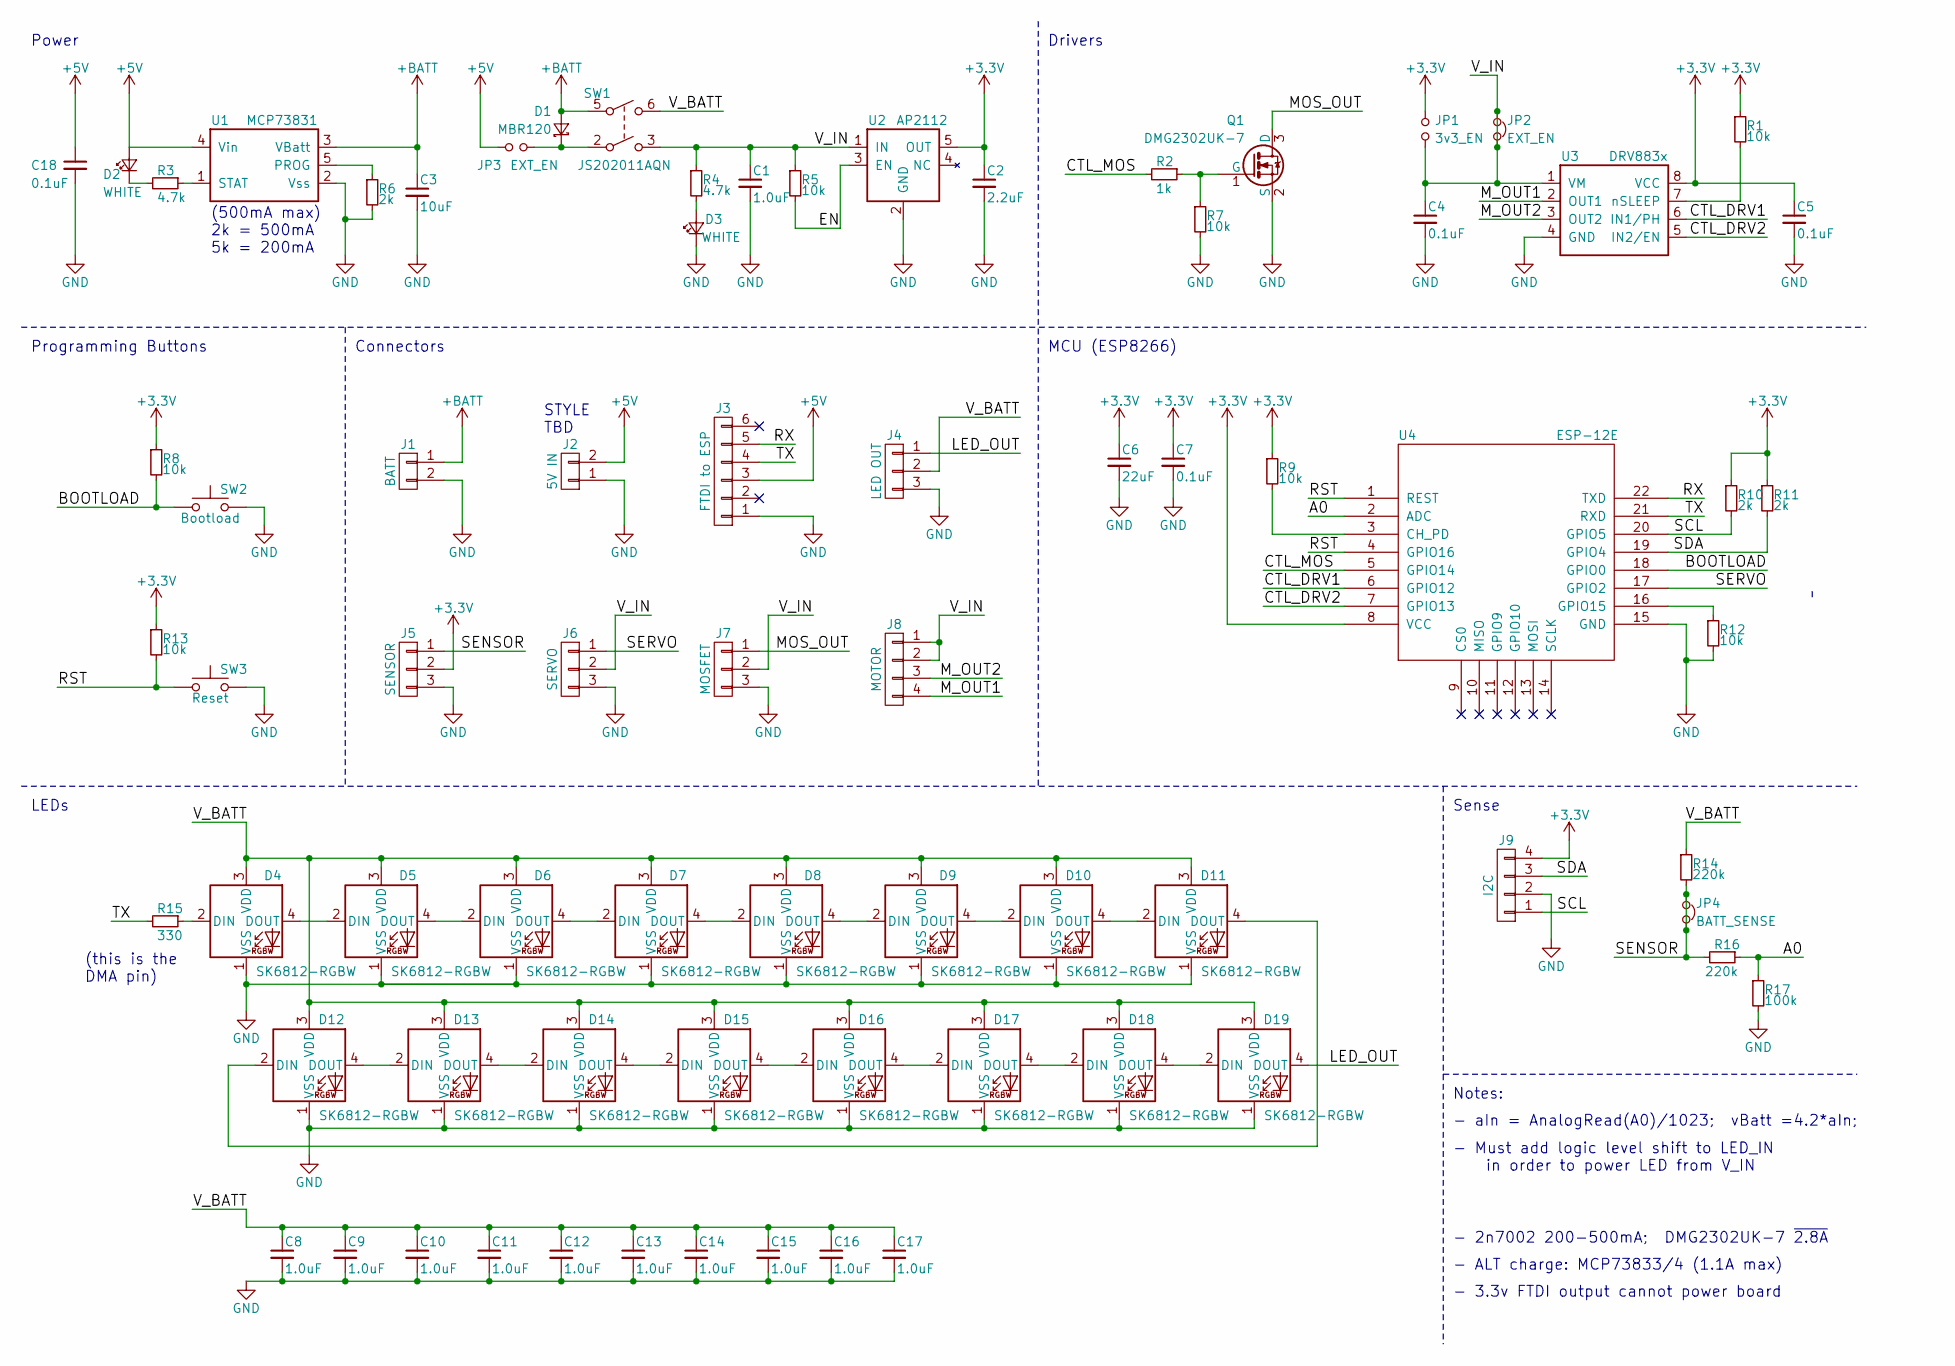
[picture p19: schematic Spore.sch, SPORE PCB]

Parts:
C1, C8, C9, C10, C11, C12, C13, C14, C15, C16, C17: 1.0uF; C_0805
C2: 2.2uF; C_0805
C3: 10uF; C_0805
C4, C5: 0.1uF; C_0603
C6: 22uF; C_0805
C7, C18: 0.1uF; C_0805
D1: MBR120; SOD-123F
D2, D3: WHITE; LED_0805
D4, D5, D6, D7, D8, D9, D10, D11, D12, D13, D14, D15, D16, D17, D18, D19: SK6812-RGBW; LED_SK6812_PLCC4_5.0x5.0mm_P3.2mm
J1: BATT; JST_PH_B2B-PH-K_02x2.00mm_Straight
J2: 5V IN; JST_EH_S02B-EH_02x2.50mm_Angled
J3: FTDI to ESP; Pin_Header_Straight_1x06_Pitch2.54mm
J4: LED OUT; JST_EH_B03B-EH-A_03x2.50mm_Straight
J5: SENSOR; JST_EH_B03B-EH-A_03x2.50mm_Straight
J6: SERVO; JST_EH_B03B-EH-A_03x2.50mm_Straight
J7: MOSFET; JST_EH_B03B-EH-A_03x2.50mm_Straight
J8: MOTOR; JST_EH_B04B-EH-A_04x2.50mm_Straight
J9: I2C; JST_EH_B04B-EH-A_04x2.50mm_Straight
JP1: 3v3_EN; JMP_NO
JP2: EXT_EN; JMP
JP3: EXT_EN; JMP_NO
JP4: BATT_SENSE; JMP
Q1: DMG2302UK-7; SOT-23
R1: 10k; C_0603
R2: 1k; C_0805
R3, R4: 4.7k; C_0805
R5, R7, R8, R9, R12, R13: 10k; C_0805
R6, R10, R11: 2k; C_0805
R14, R16: 220k; C_0805
R15: 330; C_0805
R17: 100k; C_0805
SW1: JS202011AQN; SW_Micro_DPDT
SW2: Bootload; SW_SPST_PTS645
SW3: Reset; SW_SPST_PTS645
U1: MCP73831; SOT-23-5
U2: AP2112; SOT-23-5
U3: DRV883x; DFN-8-1EP_2x2mm_Pitch0.5mm
U4: ESP-12E; ESP-12E_Brendan

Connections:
+3V3: C2.1, C5.1, C6.1, C7.1, J5.2, J9.4, JP1.1, R1.1, R8.1, R9.1, R10.1, R11.1, R13.1, U2.5 (OUT), U3.8 (VCC), U4.8 (VCC)
+5V: C18.1, D2.2 (A), J2.2, J3.3, JP3.1, U1.4 (Vin)
+BATT: C3.1, D1.2 (A), J1.1, SW1.5, U1.3 (VBatt)
/A0: R16.1, R17.1, U4.2 (ADC)
/BOOTLOAD: R8.2, SW2.1, U4.18 (GPIO0)
/CTL_DRV1: U3.6 (IN1/PH), U4.6 (GPIO12)
/CTL_DRV2: U3.5 (IN2/EN), U4.7 (GPIO13)
/CTL_MOS: R2.2, U4.5 (GPIO14)
/EN: R5.2, U2.3 (EN)
/LED_OUT: D19.4 (DOUT), J4.1
/MOS_OUT: J7.1, Q1.3 (D)
/M_OUT1: J8.4, U3.2 (OUT1)
/M_OUT2: J8.3, U3.3 (OUT2)
/RST: R13.2, SW3.1, U4.1 (REST), U4.4 (GPIO16)
/RX: J3.5, U4.22 (TXD)
/SCL: J9.1, R10.2, U4.20 (GPIO5)
/SDA: J9.3, R11.2, U4.19 (GPIO4)
/SENSOR: J5.1, JP4.1, JP4.2, R14.2, R16.2
/SERVO: J6.1, U4.17 (GPIO2)
/TX: J3.4, R15.2, U4.21 (RXD)
/V_BATT: C8.1, C9.1, C10.1, C11.1, C12.1, C13.1, C14.1, C15.1, C16.1, C17.1, D4.3 (VDD), D5.3 (VDD), D6.3 (VDD), D7.3 (VDD), D8.3 (VDD), D9.3 (VDD), D10.3 (VDD), D11.3 (VDD), D12.3 (VDD), D13.3 (VDD), D14.3 (VDD), D15.3 (VDD), D16.3 (VDD), D17.3 (VDD), D18.3 (VDD), D19.3 (VDD), J4.2, R14.1, SW1.6
/V_IN: C1.1, C4.1, J6.2, J7.2, J8.1, J8.2, JP1.2, JP2.1, JP2.2, R4.1, R5.1, SW1.3, U2.1 (IN), U3.1 (VM)
GND: C1.2, C2.2, C3.2, C4.2, C5.2, C6.2, C7.2, C8.2, C9.2, C10.2, C11.2, C12.2, C13.2, C14.2, C15.2, C16.2, C17.2, C18.2, D3.1 (K), D4.1 (VSS), D5.1 (VSS), D6.1 (VSS), D7.1 (VSS), D8.1 (VSS), D9.1 (VSS), D10.1 (VSS), D11.1 (VSS), D12.1 (VSS), D13.1 (VSS), D14.1 (VSS), D15.1 (VSS), D16.1 (VSS), D17.1 (VSS), D18.1 (VSS), D19.1 (VSS), J1.2, J2.1, J3.1, J4.3, J5.3, J6.3, J7.3, J9.2, Q1.2 (S), R6.2, R7.2, R12.2, R17.2, SW2.2, SW3.2, U1.2 (Vss), U2.2 (GND), U3.4 (GND), U3.9 (GND), U4.15 (GND)
unnamed: D1.1 (K), JP3.2, SW1.2
unnamed: D2.1 (K), R3.2
unnamed: D3.2 (A), R4.2
unnamed: D4.2 (DIN), R15.1
unnamed: D4.4 (DOUT), D5.2 (DIN)
unnamed: D5.4 (DOUT), D6.2 (DIN)
unnamed: D6.4 (DOUT), D7.2 (DIN)
unnamed: D7.4 (DOUT), D8.2 (DIN)
unnamed: D8.4 (DOUT), D9.2 (DIN)
unnamed: D9.4 (DOUT), D10.2 (DIN)
unnamed: D10.4 (DOUT), D11.2 (DIN)
unnamed: D11.4 (DOUT), D12.2 (DIN)
unnamed: D12.4 (DOUT), D13.2 (DIN)
unnamed: D13.4 (DOUT), D14.2 (DIN)
unnamed: D14.4 (DOUT), D15.2 (DIN)
unnamed: D15.4 (DOUT), D16.2 (DIN)
unnamed: D16.4 (DOUT), D17.2 (DIN)
unnamed: D17.4 (DOUT), D18.2 (DIN)
unnamed: D18.4 (DOUT), D19.2 (DIN)
unnamed: Q1.1 (G), R2.1, R7.1
unnamed: R1.2, U3.7 (nSLEEP)
unnamed: R3.1, U1.1 (STAT)
unnamed: R6.1, U1.5 (PROG)
unnamed: R9.2, U4.3 (CH_PD)
unnamed: R12.1, U4.16 (GPIO15)

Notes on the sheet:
Power
MCU (ESP8266)
Programming Buttons
- 2n7002 200-500mA; DMG2302UK-7 ~2.8A
- aIn = AnalogRead(A0)/1023; vBatt =4.2*aIn;
(500mA max) 2k = 500mA 5k = 200mA
- ALT charge: MCP73833/4 (1.1A max)
Connectors
- Must add logic level shift to LED_IN in order to power LED from V_IN
- 3.3v FTDI output cannot power board
Drivers
LEDs
Sense
Notes:
STYLE TBD
(this is the DMA pin)

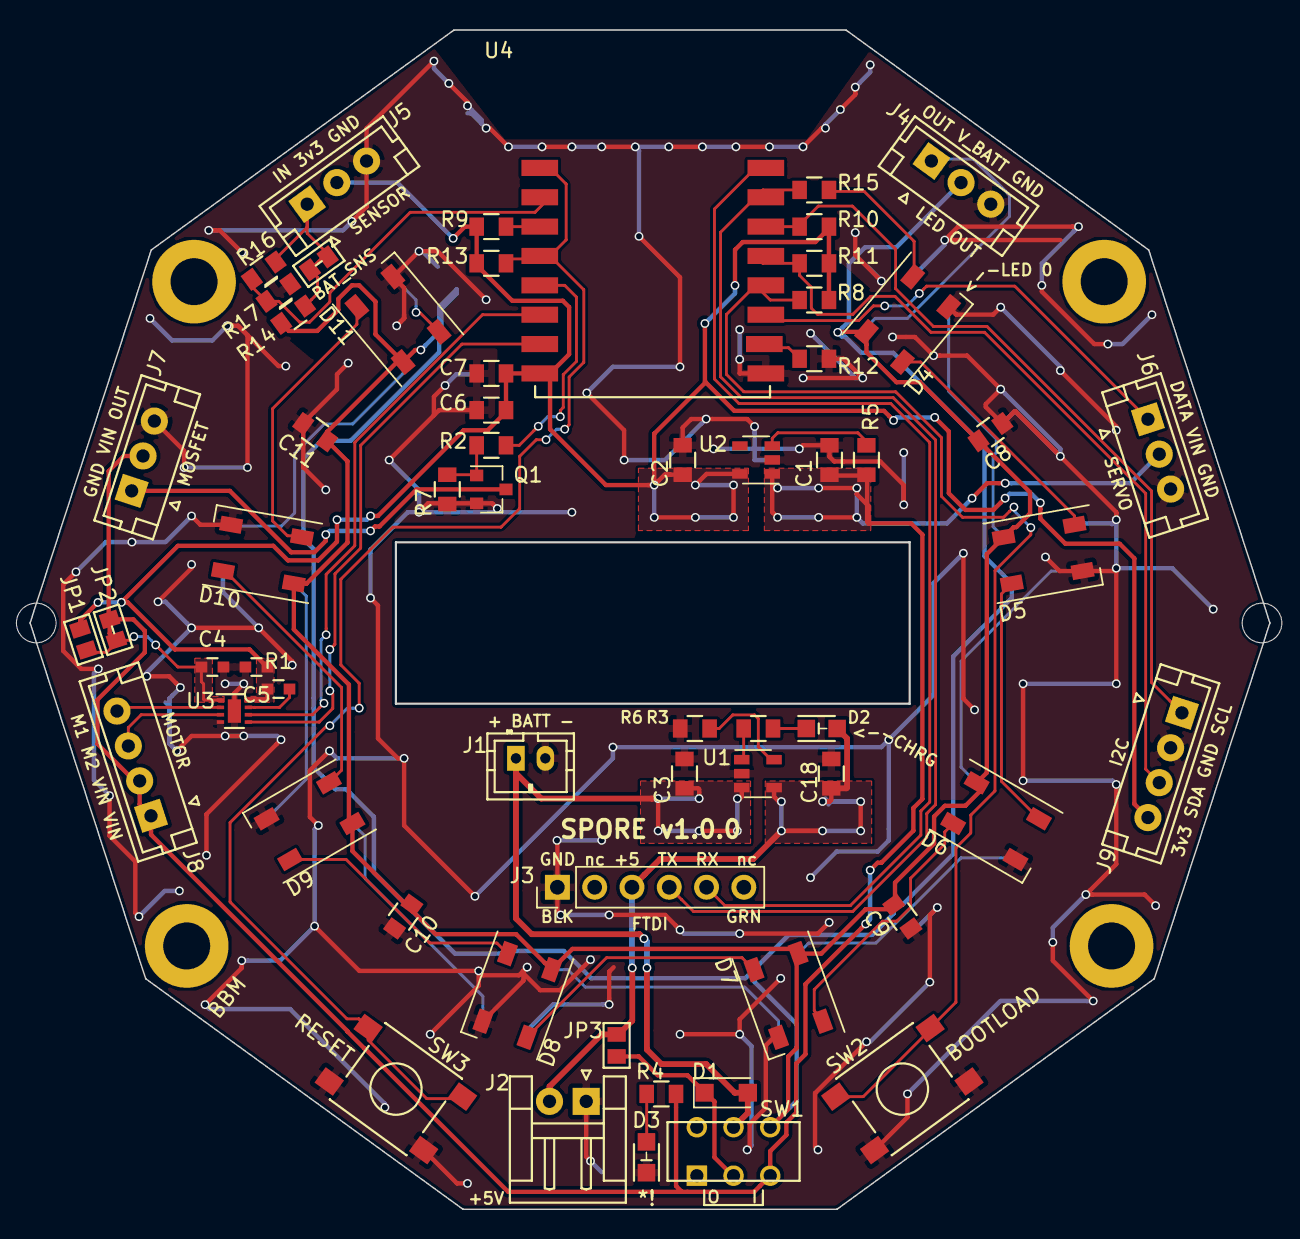
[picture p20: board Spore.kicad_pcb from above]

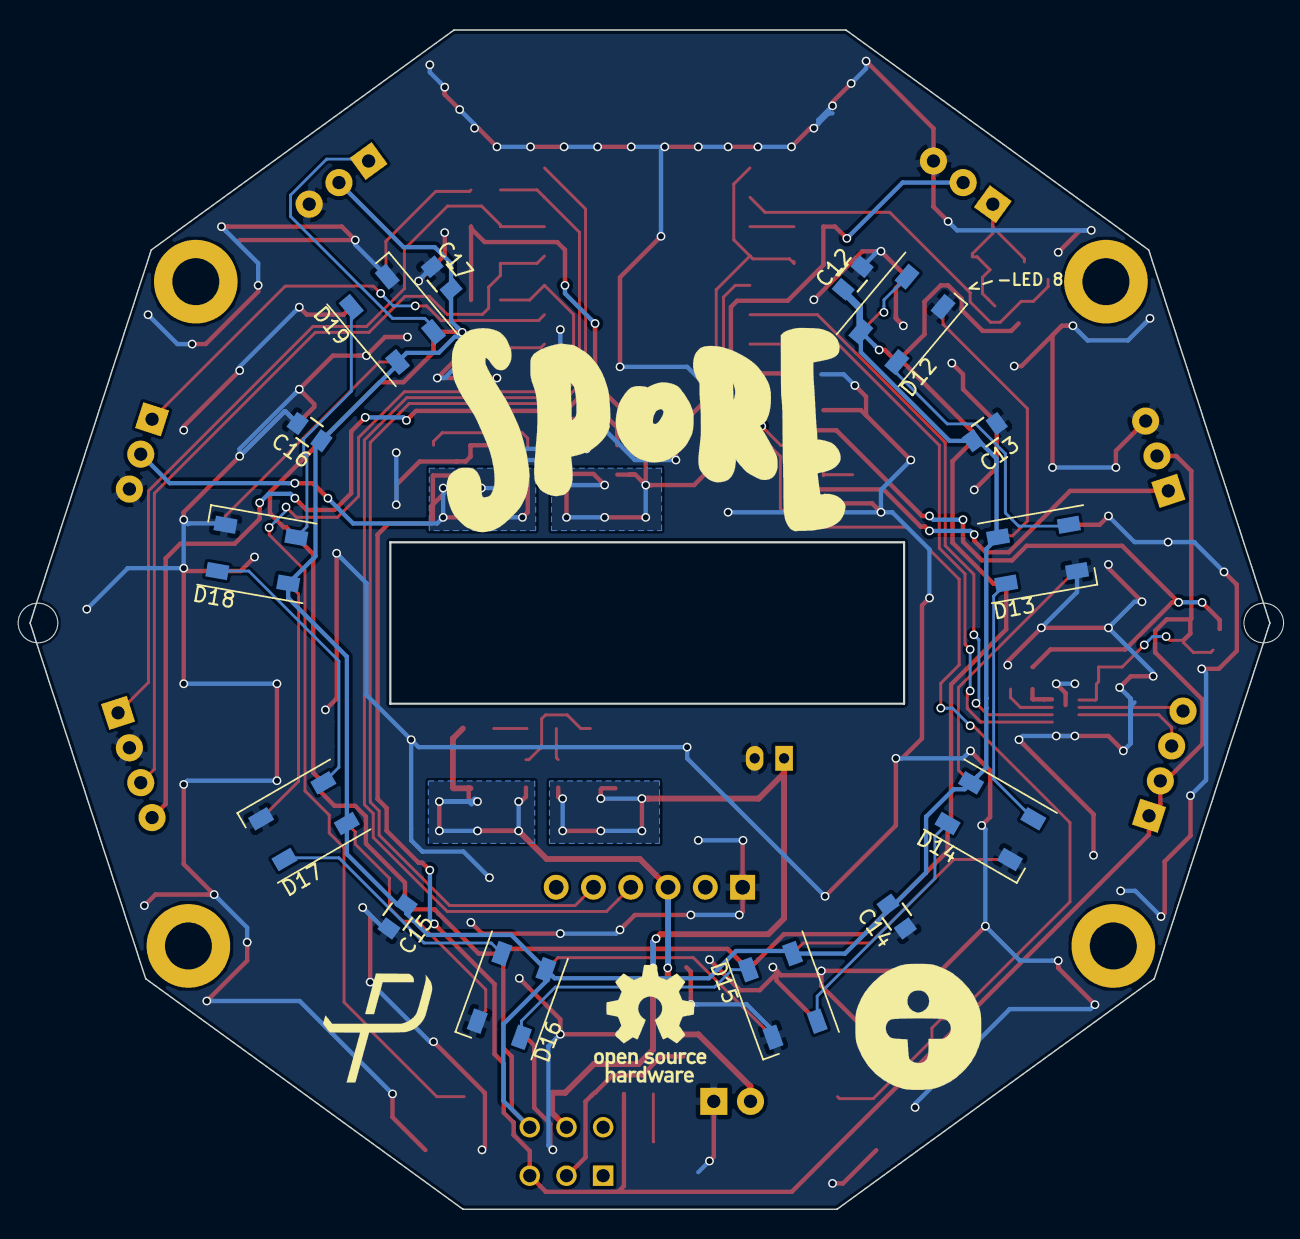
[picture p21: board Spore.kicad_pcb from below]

Board: 2 copper layers, 84.5 x 80.3 mm, 75 parts (14 on the bottom side), 48 nets.

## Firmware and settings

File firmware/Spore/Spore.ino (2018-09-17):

/*
    SPORE FIRMWARE
    Copyright (C) 2018 PWRFL

    @authors Tim Rolls, and Brendan Matkin

    This sketch contains the firmware for the "Spore" hardware.
    The intent is to create an installation that periodically remaps wireless LEDs ("Spores")
    and fascilitates an interactive element.

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
    You should have received a copy of the GNU General Public License
    along with this program.  If not, see <https://www.gnu.org/licenses/>.
*/

/*
   USE ESP8266 Arduino Core v2.4.2 (https://github.com/esp8266/Arduino)
   Board: NodeMCU v1.0
   Flash Size: 4M (1M SPIFFS)
   Upload Speed: 230400   --this works consistentnly with classic FTDI. Newer chips may work at 921600
*/


extern "C" {
  #include "user_interface.h"           // allows wifi_set_sleep_type
}

#include "settings.h"                   // local settings!
#include "otaFirmware.h"                // over the air firmware updates!
#include "serverControl.h"
//#include "FS.h"                       // File System / SPIFFS
#include <NeoPixelBus.h>
#include <FastLED.h>
//#include <ESP8266WiFiMulti.h>         // alternate to wifimanager - no portal but remembers multiple access points
#include <E131.h>                       // sACN (e1.31) library

/*  switch to async??? https://github.com/forkineye/ESPAsyncE131
    uses this: https://github.com/me-no-dev/ESPAsyncUDP
*/


#define LED_BUILTIN   2                 // not correctly mapped for ESP-12x
#define BOOTLOAD_PIN  0                 // BOOTLOAD button



const uint16_t PixelCount = 16;                                   // DO NOT CHANGE!!
NeoGamma<NeoGammaTableMethod> colorGamma;                         // for any fade animations, best to correct gamma
NeoPixelBus<NeoGrbFeature, Neo800KbpsMethod> pixels(PixelCount);  // This is DMA so uses GPIO 3 (alawys same physical pin as U0RXD)

E131 e131;                              // sACN library
WiFiUDP udp;


/******** MISC *********/

void fadeAll(uint8_t darkenBy) {
    RgbColor col;
    for (uint16_t i = 0; i < pixels.PixelCount(); i++) {
        col = pixels.GetPixelColor(i);
        col.Darken(darkenBy);
        pixels.SetPixelColor(i, col);
    }
}




/******** SETUP ********/

void setup() {
  wifi_set_sleep_type(NONE_SLEEP_T);          // disable wifi sleep (added this when trying to fix analogRead issue.. is it still needed?)
  Serial.begin(115200);
  delay(200);
  Serial.printf("\n\n\nSPORE\n");
  Serial.printf("FW: %u%s   ", FW_VERSION, FW_PHASE);
  Serial.printf("HW: %s%s\n", HW_VERSION, HW_PHASE);
  Serial.printf("(c)2018 PWRFL\n\n");         // pick open source license

  EEPROM.begin(512);              // address = 0, ip = 1,2,3,4, mode = 5
  //EEPROM.get(0, address);
  address = EEPROM.read(0);
  deviceName.concat(address);
  for (int i = 0; i < 4; i++) {
    serverIP[i] = EEPROM[i+1];    // + 1 because "address" is stored at 0
  }
  //currentMode = (Mode)EEPROM[5];    // see bottom of setup()

  /* LEDs */
  delay(100);
  pixels.Begin();
  for (int i = 0; i < PixelCount; i++) {
    pixels.SetPixelColor(i, RgbColor(0));
  }
  pixels.Show();

  /* connect to WiFi */
  Serial.printf("[INFO] Connecting to: ");
  Serial.print(ssid);
  WiFi.persistent(false);                   // don't re-write ssid/password to flash every time (avoid degredation)
  WiFi.mode(WIFI_STA);                        // without this ESP will be station and AP at the same time - this can give you headaches!!!
  WiFi.hostname(deviceName);                  // DHCP Hostname    -- does this even work?!
  //WiFi.config(staticIP, gateway, subnet);   // set static IP, defaults to DHCP if config not called
  WiFi.begin(ssid, password);                 // connect to your existing network
  int restartCounter = 0;
  while (!WiFi.isConnected()) {               // auto reset if it's not connecting (occasionally hangs otherwise)
    delay(100); Serial.print(".");
    restartCounter++;
    if (restartCounter > 70) ESP.restart();   // if it takes more than 5 (50x100ms) seconds to connect, restart!
  }
  Serial.printf("  connected.\n");            // yay it worked!

  /* init LED PIN */
  pinMode(LED_BUILTIN, OUTPUT);
  digitalWrite(LED_BUILTIN, HIGH);             // low is on


  /* sACN
     The e131.begin() method creates the UDP port and joins the multicast group for you. */
  Serial.printf("Starting sACN: ");
  e131.begin(E131_MULTICAST, 1, 1);           // (E131_UNICAST <or> E131_MULTICAST, universeNumber, number of universes)

  /* setup websockets */
  webSocket.begin(serverIP.toString(), wsPort, "/");
  webSocket.onEvent(webSocketEvent);
  webSocket.setReconnectInterval(5000);       // TODO: Do I need to manually ping/pong??

  /* udp listen */
  if (udp.begin(oscPort)) {
    Serial.printf("Opened unicast OSC port\n");
  }
  else {
    Serial.printf("Open OSC prt failed\n");
  }

  /* who am I this time?  */
  delay(100);
  Serial.printf("\nConnection details:\n");
  Serial.printf("IP address:  ");
  Serial.println(WiFi.localIP());
  Serial.printf("sACN address: %u\n", address);
  Serial.printf("Listening to Websocket server at: %s:%u\n", serverIP.toString().c_str(), wsPort);
  Serial.printf("Listening to unicast OSC at port: %u\n", oscPort);
  Serial.printf("%s (%s) ready. \n", deviceName.c_str(), WiFi.macAddress().c_str());
  Serial.printf("\n---\n\n");

  //currentMode = TEST;
  currentMode = (Mode)EEPROM[5];
  yield();
}




/******** LOOP ********/

void loop() {
  //webSocket.loop();                           // remove for async
  static uint32_t pingTimer;
  if (millis() - pingTimer > pingInterval) {
    webSocket.sendPing();                       // ping server to recognize a dropped TCP connection
    pingTimer = millis();
  }


  switch(currentMode) {
    case TEST: {
      if (e131.parsePacket()) {
        // always parse udp data to avoid buffer overflows and subsequent random crashing
      }
      static uint32_t testTimer;
      if (millis() - testTimer > 12) {
        testStepper++;
        testTimer = millis();
        pixels.RotateLeft(1);
      }
      uint8_t _step = testStepper;
      for (int i = 0; i < PixelCount; i++) {
        HsbColor col = HsbColor(0.6, 0.30, cubicwave8( _step+i*5 )/255.0f);      // pulse with a blink (as testStepper rolls over)
        pixels.SetPixelColor(i, col);
      }
      
      pixels.Show();
      break;
    }
    
    case SLEEP: {   // for now this is blackout!
      if (e131.parsePacket()) {
        // always parse udp data to avoid buffer overflows and subsequent random crashing
      }
      RgbColor col = RgbColor(0, 0, 0);
        for (int i = 0; i < PixelCount; i++) {
          pixels.SetPixelColor(i, col);
        }
      pixels.Show();
      break;
    }
    
    case NORMAL:    // for now these all do the same thing!
    default:
      /* sACN receive: */
      static uint32_t receiveTimer;
      static uint32_t fadeTimer;
      if (millis() - receiveTimer > receiveTimeout) {       // if we havent received a packet for <receiveTimeout>ms, then fade to black
        if (millis() - fadeTimer > 6) {                     // 5 is the fade speed - lower number ot fade out faster
          fadeAll(1);
          fadeTimer = millis(); 
        }
      }
      
      if (e131.parsePacket()) {
        receiveTimer = millis();
        /* NOTE: ADDRESSES SHOULD PROBABLY START AT 0 IF WE ARE NOT DERIVING THEM FROM OR ASSIGNING THEM TO IP ADDRESSES */
        uint8_t r = e131.data[address * CHAN_PER_FIXTURE];         // address starts at 0
        uint8_t g = e131.data[address * CHAN_PER_FIXTURE + 1];
        uint8_t b = e131.data[address * CHAN_PER_FIXTURE + 2];
        RgbColor col = colorGamma.Correct(RgbColor(r, g, b));
        for (int i = 0; i < PixelCount; i++) {
          pixels.SetPixelColor(i, col);
        }
        digitalWrite(LED_BUILTIN, HIGH);            // (low is on)
      }
      pixels.Show();
      break; 
  }


  /* OSC receive (for server config): */
  //noInterrupts();
  int udpSize = udp.parsePacket();
  //interrupts();
  if (udpSize > 0) {
    OSCMessage inMsg;
    while (udpSize--) {
      inMsg.fill(udp.read());
    }
    if (!inMsg.hasError()) {
      inMsg.route("/server", updateServerIP);
      inMsg.route("/restart", restartOSC);
    }
  }

  /* battery voltage: */
  static float vRaw;
  static uint32_t analogReadTimer;
  if (millis() - analogReadTimer > 1000) {       // 200 = 5 per second. can't analogRead too fast or wifi disconnects. 
    vRaw = analogRead(A0);
    vRaw = (vRaw / 1023.0f) * 5.31;             // 5.31 is the calibration value for the new voltage divider (range goes below 0) May vary with resistor tolerance..
    delay(3);                                   // this delay HAS to be here. No Flickers! (Thanks to DMA)
    float coef = 0.25;
    batteryVoltage = vRaw * coef + (1.0f - coef) * batteryVoltage;

    char battJSON[jsonSendSize];
    serializeJSON_battery(battJSON);
    webSocket.sendTXT(battJSON);        // send to server
    analogReadTimer = millis();
  }
  


  /* Handle OTA FIRMARE updates: */
  if (checkForFW) {
    checkForNewFirmware(fwUrlBase, fwFilename);
    checkForFW = false;
  }

  digitalWrite(LED_BUILTIN, HIGH);              // turn off LED at the end of every loop (low is on)
  yield();
}


/*
  e131 sample parse:
  uint16_t numChannels = e131.parsePacket();
  if (numChannels > 0) {
    Serial.printf("Universe %u / %u Channels | Packet#: %u / Errors: %u / CH1: %u\n",
                  e131.universe,              // The Universe for this packet
                  numChannels,                // Number of channels in this packet
                  e131.stats.num_packets,     // Packet counter
                  e131.stats.packet_errors,   // Packet error counter
                  e131.data[0]);              // Dimmer data for Channel 1
  }
*/

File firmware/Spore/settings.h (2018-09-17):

#ifndef SETTINGS_H
#define SETTINGS_H


#include <ESP8266WiFi.h>
#include <ESP8266mDNS.h>    // necessary?
#include <WiFiUDP.h>
#include <EEPROM.h>

#include "wifi_config.h"   
// to track and stop tracking config.h: 
// git update-index --assume-unchanged FILE_NAME 
// git update-index --no-assume-unchanged FILE_NAME

//#include <WebSocketsClient.h>
#include "src/lib/WebSockets/src/WebSocketsClient.h"  // setup for async (~line 90 of WebSockets.h). why this folder structure?: https://forum.arduino.cc/index.php?topic=445230.0
WebSocketsClient webSocket;


/* -- network settings -- */
const char* AP_SSID  = "SPORE-TEST";
const char* ssid     = WIFI_SSID;         // ssid from wifi_config.h
const char* password = WIFI_PASSWORD;     // password from wifi_config.h
String deviceName    = "Spore_";          // used for DHCP
IPAddress serverIP(10, 10, 10, 100);      // server IP address
uint16_t wsPort      = 8080;              // websocket connection port
uint16_t oscPort = 7777;                  // osc listen port to receive server config broadcast


/* -- firmware settings -- */
#define HW_VERSION "1.0.0"
#define HW_PHASE   ""
const int FW_VERSION = 308;              // 0.3.00, convention: 1.2.10 = 1210, 0.5.9 = 509, no leading 0s or it is interpreted as octal.. learned that the hard way!
#define FW_PHASE   "-beta"
//float fwCheckButtonTime = 2000.0f;     // how long to hold button down.


/* -- general settings -- */
#define CHAN_PER_FIXTURE 3               // number of channels per fixture
volatile uint8_t address = 99;
const uint32_t pingInterval = 5000;
const uint32_t receiveTimeout = 3000;    // how long before fade to black after no signal


enum Mode : uint8_t {
  NORMAL = 0,
  TEST = 1,
  SLEEP = 2
};
volatile Mode currentMode;


/* -- OTA firmware global settings -- */
bool checkForFW = false;
String fwUrlBase;
String fwFilename;

float batteryVoltage = 3.7;               // assume nominal voltage to start 

#endif /* SETTINGS_H */

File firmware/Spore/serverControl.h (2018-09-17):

#ifndef SERVER_CONTROL_H
#define SERVER_CONTROL_H

/*
  websocket terminal client:
  > npm install -g wscat
  > wscat -c <serverIP>:8080
*/

#include <ArduinoJson.h>
#include <Hash.h>
#include "OSCMessage.h"



// eg. message types in server
//const MSG_TYPE_SET_ADDRESS      = 0
//const MSG_TYPE_SET_MODE         = 1
//const MSG_TYPE_CHECK_FIRMWARE   = 2
//const MSG_TYPE_CONFIG           = 3
//const MSG_TYPE_REBOOT           = 4
//const MSG_TYPE_SCAN             = 5
//const MSG_TYPE_REQUEST_ADDRESS  = 6
//const MSG_TYPE_CONNECT_INFO     = 7
//const MSG_TYPE_BATTERY          = 8

enum MsgType : uint8_t  {
  SET_ADDRESS = 0,
  SET_MODE,
  CHECK_FIRMWARE,
  CONFIG,
  REBOOT,
  SCAN,
  REQUEST_ADDRESS,
  CONNECT_INFO,
  BATTERY
};
volatile uint8_t testStepper = 0;      // for the test fade cycle


/* ---- OSC Callback (server IP): ---- */
void updateServerIP(OSCMessage &msg, int addressOffset) {
  bool _serverChanged = false;
  for (int i = 0; i < 4; i++) {
    if (msg.isInt(i)) {
      serverIP[i] = msg.getInt(i);
      if (serverIP[i] != EEPROM[i+1]) {
        EEPROM[i+1] = serverIP[i];
        _serverChanged = true;
      }
    }
  }
  if (_serverChanged) {
    EEPROM.commit();
    webSocket.begin(serverIP.toString(), wsPort, "/");
    Serial.printf("[osc] New Websocket server at: %s:%u\n", serverIP.toString().c_str(), wsPort);
    //delay(10);
    yield();
    ESP.restart();
  }
  else {
    Serial.printf("[osc] websocket server unchanged\n");
  }
}
/* ---- OSC Callback (restart): ---- */
void restartOSC(OSCMessage &msg, int addressOffset) {
  if (msg.isInt(0)) {
    if (msg.getInt(0)) {
      // reserved for future use
    }
  }
  Serial.printf("[osc] received OSC-based restart (probably broadcast, probably because some of us are not behaving)\n");
  ESP.restart();
}


/* ---- websocket<-->JSON functions ---- */
const uint16_t jsonSendSize = 256;
void serializeJSON_connected(char * json) {
  StaticJsonBuffer<jsonSendSize> jsonBuffer;
  JsonObject& root = jsonBuffer.createObject();
  root["type"] = (uint8_t)CONNECT_INFO;
  JsonObject& data = root.createNestedObject("data");
  data["address"] = (uint8_t)address;
  data["firmwareVersion"] = FW_VERSION;
  root.printTo(json, jsonSendSize);
  Serial.println(json);
}

void serializeJSON_scan(char * json) {
  StaticJsonBuffer<jsonSendSize> jsonBuffer;
  JsonObject& root = jsonBuffer.createObject();
  root["type"] = (uint8_t)REQUEST_ADDRESS;
  root["data"] = WiFi.macAddress();
  root.printTo(json, jsonSendSize);
  Serial.println(json);
}

void serializeJSON_battery(char *json) {
  StaticJsonBuffer<jsonSendSize> jsonBuffer;
  JsonObject& root = jsonBuffer.createObject();
  root["type"] = (uint8_t)BATTERY;
  root["data"] = batteryVoltage;
  root.printTo(json, jsonSendSize);
  //Serial.println(json);
}

bool deserializeJSON(uint8_t * json) {
  StaticJsonBuffer<512> jsonBuffer;     // actually only needs to be about 240 bytes, extra reserved for future use (or just because I have the space..). (http://arduinojson.org/assistant/)
  JsonObject& root = jsonBuffer.parseObject(json);
//const char* exampleNestedValue = root["object"]["key"];
//const char* exampleValue = root["key"];
  if (!root.success()) {
    Serial.printf("[ws] JSON parseObject() failed.\n");
    return false;
  }
  else {
    uint8_t _type = root["type"];
    MsgType type = (MsgType)_type;
    switch (type) {
      case SET_ADDRESS: {
          uint8_t _addr = root["data"];                     // ** placeholder **
          address = _addr;
          EEPROM.write(0, address);
          EEPROM.commit();
          Serial.printf("[ws] <SET_ADDRESS>: %u\n", address);
        }
        break;
      case SET_MODE: {
          uint8_t _mode = root["data"];                     // ** placeholder **
          Serial.printf("[ws] <SET_MODE>: ");
          currentMode = (Mode)_mode;
          switch (currentMode) {
            case NORMAL: {
                Serial.printf("NORMAL\n");
              }
              break;
            case TEST: {
                testStepper = 0;
                Serial.printf("TEST\n");
              }
              break;
            case SLEEP: {
                Serial.printf("SLEEP\n");
              }
            break;
            default:
              Serial.printf("err: (unknown mode)\n");
              break;
          }
//          Serial.printf("[ws] <SET_MODE>: %u\n", _mode);
        }
        break;
      case CHECK_FIRMWARE: {
          uint16_t newFirmwareVersion = root["data"]["version"];
          fwUrlBase = root["data"]["url"].as<String>();
          fwFilename = root["data"]["filename"].as<String>();
          Serial.printf("[ws] <CHECK_FIRWMARE>: %s%s, current version/new version: %u/%u\n", fwUrlBase.c_str(), fwFilename.c_str(), FW_VERSION, newFirmwareVersion);

          // set flag and do check in the loop, otherwise http-client fails to connect (maybe a buffer overrun from async)
          if (newFirmwareVersion > FW_VERSION) {
            webSocket.disconnect();                 // THIS IS PROBABLY NOT NECESSARY
            checkForFW = true;
          }
          else {
            Serial.println("[OTA] Already using latest version");
          }
        }
        break;
      case CONFIG: {
          // example
          // (not 100% sure yet if/how we'll use config)
          uint8_t _newSSID = root["data"]["ssid"];          // ** placeholder **
          uint8_t _newPass = root["data"]["password"];      // ** placeholder **
          uint8_t startMode = root["data"]["startmode"];
          EEPROM[5] = startMode;
          EEPROM.commit();
          Serial.printf("[ws] <CONFIG>: %u, %u, %u\n", _newSSID, _newPass, startMode);
        }
        break;
      case REBOOT:
        Serial.printf("\n\n[ws] <REBOOT> Rebooting now!");
        ESP.restart();
        break;
      case SCAN:
        Serial.printf("[ws] <SCAN> sending REQUEST_ADDRESS\n");
        char scanJSON[jsonSendSize];
        serializeJSON_scan(scanJSON);
        webSocket.sendTXT(scanJSON);        // send to server
        break;
      default:
        Serial.printf("[ws] err: Unrecognized Message Type\n");
        break;
    }
  }
  return root.success();
}
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

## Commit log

2018-03-08 initial commit. v0.0.1 of prototype schematic done
    [Spore_proto.kicad_pcb, Spore_proto.sch, _saved_field.sch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]
2018-03-08 aesthetic adjustments + footprint assignment
    [Spore_proto.sch]
2018-03-14 added power switch (allows charging while off), minor tweaks, footprint assignments
    [Spore_proto.sch]
2018-03-14 few tweaks. Pre-PCBNew
    [Spore_proto.sch]
2018-03-14 import netlist into pcbnew + separate components
2018-03-15 basic pcb layout done
    [Spore_proto.kicad_pcb]
2018-03-16 complex pcb layout + some footprint changes
    [Spore_proto.kicad_pcb, Spore_proto.sch]
2018-03-30 gerbers, BOM, etc for PCB fab
    [Spore_proto.csv, Spore_proto.kicad_pcb, Spore_proto_BOM.xlsx]
2018-05-23 simple wifimanager auto-config + led init
2018-05-25 added v0.0.3 BOM
    [Spore_BOM_v0.0.3.xlsx]
2018-05-25 cleanup after combining repos
    [PCB_mm.dxf, Spore_BOM_v0.0.3.xlsx, Spore_proto.csv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]
2018-05-25 tidy up file structure of EDA stuff
    [PCB_mm.dxf, Spore_BOM_v0.0.3.xlsx, Spore_proto.csv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]
2018-05-31 some PCB schematic revisions for final hardware
    [Spore.sch]
2018-05-31 added local OTA uploads (direct from Arduino IDE)
2018-05-31 removed simple ArduinoOTA (slow and unreliable). Will implement server style
2018-05-31 added sACN to LEDs (as a single pixel) + cleanup
2018-05-31 switch to manual wifi for now
2018-06-07 updated schematic in prep for next H/W version
    [Spore.sch]
2018-06-07 PCB layout - new battery & bigger antenna keepout
    [Spore.kicad_pcb]
2018-06-07 fixed batt pinout to match h/w v0.0.3 (it's schematic didn't match)
    [Spore.sch]
2018-06-07 nearly finished v1 hardware -- need to finish ground stitching
    [Spore.kicad_pcb, Spore.sch]
2018-06-09 finished grounds and via stitching (PCB)
    [Spore.kicad_pcb]
2018-06-09 added mounted holes to PCB and finalized ground stitching.
    [Spore.kicad_pcb]
2018-06-09 added mounting notches
    [Spore.kicad_pcb]
2018-06-10 export v1.0.0 gerbers
    [Spore-B.Cu.gbl, Spore-B.Mask.gbs, Spore-B.Paste.gbp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]
2018-06-22 cleanup Arduino + add server (websocket+JSON) framework
2018-06-22 some weird random changes to the EDA files I don't want to deal with
    [#PCB_mm.dxf, SPORE_PCB_mm.dxf, Spore_BOM_v0.0.3.xlsx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]
2018-08-03 exported 3D model of PCB (.vrml)
2018-08-07 switch to websockets async
2018-08-22 switch to 2.4.2 and added ws setMode
2018-08-22 added MODE buttons to UI that send websocket message
2018-08-22 switch branch
2018-08-22 fix server addressing complete + change server IP in firmware
    [settings.h]
2018-08-24 added monitor window (currently empty).
2018-08-24 added button hovers
2018-08-25 tx/rx battery volts and update in UI as percent
2018-08-25 cleanup server battery logic
2018-09-12 cleanup css. fontawesome offline. tidy battery logic on server
2018-09-15 re-mapped battery range (now 3.3-4.2) and added plug-in warning
2018-09-15 working workaround (maybe the real fix) for multiple handshakes from single devices (and stuck in handshake loops)
2018-09-17 different view of "X devices connected" message
2018-09-17 finished implementing config from server (current config sets start mode). also tweaked remote restart logic
2018-09-25 renamed folders
    [#PCB_mm.dxf, PCB_mm.dxf, SPORE_PCB_mm.dxf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]
2018-09-25 Added enclosure files
    [Spore Shell 1 of 2.stp, Spore Shell 2 of 2 ( with slot ).stp, Spore Solid.stp]
2021-11-10 Update README.md
    https://forum.kicad.info/t/warning-avoid-all-links-to-kicad-pcb-org-use-kicad-org/31521

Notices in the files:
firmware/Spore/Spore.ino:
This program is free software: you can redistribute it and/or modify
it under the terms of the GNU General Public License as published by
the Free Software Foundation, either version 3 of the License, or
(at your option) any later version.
